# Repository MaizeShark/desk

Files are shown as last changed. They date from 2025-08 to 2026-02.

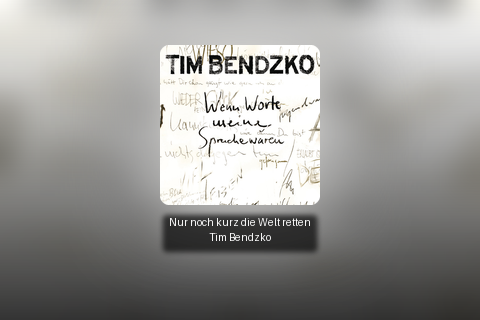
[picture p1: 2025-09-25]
htdocs/artwork.png

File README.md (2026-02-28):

# Desk

A custom-built smart L-shaped desk with deep Home Assistant integration. The project spans hardware design (custom PCBs), embedded firmware (ESP32-S3), and software services, all tied together via MQTT.

## Overview

This repository contains all the design files and software for a DIY smart desk ecosystem. The desk houses a dedicated electronics enclosure that handles audio routing, thermal management, environmental monitoring, and a media display — all controllable from Home Assistant.

```
desk/
├── PCB/            # Main KiCad PCB & schematics (ESP32-S3, DSP, DACs, PSU, …)
├── HID/            # Input device PCBs (rotary encoders, HID controller)
├── audio.md        # Audio matrix design document
├── fan_control.md  # Fan controller design document
├── Raspi/          # MPRIS-to-MQTT bridge service (Python, systemd)
└── UI/Docker/      # Media artwork generator & HTTP server (Docker)
```

---

## Sub-Projects

| | |
|---|---|
| [Audio Matrix](audio.md) | 6-in / 4-out digital audio matrix at 96 kHz / 24-bit. ADAU1451 DSP with ASRC, controlled by ESP32-S3 over I²C. Sources include USB, S/PDIF, Bluetooth (LDAC), I²S, and analog line-in. |
| [Fan Controller](fan_control.md) | ESP32-S3 reads all component temperatures via a TI TMP468 and the Raspberry Pi's CPU temp over I²C, then drives an Arctic P8 Max PWM fan based on the system hotspot. |
| [Desk GUI](https://github.com/MaizeShark/desk-gui) | ESP32-S3 firmware (PlatformIO / LVGL) for the 4-inch touchscreen control panel. Shows current track and album art, Spotify playback controls, and drives 12× addressable RGB LEDs. |
| [MPRIS → MQTT](Raspi/) | Python systemd service on the Raspberry Pi that watches the active media player via D-Bus and publishes playback state to MQTT. See [`Raspi/README.md`](Raspi/README.md). |
| [Media Artwork Service](UI/Docker/) | Dockerised service that fetches album art from Spotify / Jellyfin, composites a 480×320 image, serves it over HTTP, and publishes the URL to MQTT. See [`UI/Docker/README.md`](UI/Docker/README.md). |

---

## Hardware

The main PCB (`PCB/Tisch.kicad_pcb`) integrates all of the above subsystems onto a single board. Schematics are split into logical sheets:

| File | Content |
|---|---|
| `esp32.kicad_sch` | Main ESP32-S3 controller |
| `ADAU1451.kicad_sch` | DSP |
| `dac.kicad_sch` | PCM5122 DAC outputs |
| `adc.kicad_sch` | PCM1809 ADC input |
| `QCC5125.kicad_sch` | Bluetooth RX |
| `bm83.kicad_sch` | Bluetooth TX |
| `spdif.kicad_sch` | S/PDIF receiver |
| `raspi.kicad_sch` | Raspberry Pi interface |
| `fan.kicad_sch` | Fan control circuit |
| `psu.kicad_sch` | Power supply |
| `display.kicad_sch` | Display connector |
| `hid.kicad_sch` | HID / encoder inputs |

The `HID/` directory contains a separate PCB for the rotary encoder input device.

---

## License

This project is licensed under the **GNU General Public License v3.0**. See [`LICENSE`](LICENSE) for details.

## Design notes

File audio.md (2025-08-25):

# Project: The HA-Integrated Digital Audio Matrix

## 1. Overview

This document outlines the architecture for a high-fidelity, versatile digital audio matrix and switcher. The system is designed to manage multiple analog and digital audio sources, process them in a central DSP, and route them to various outputs. The entire system is designed to be controlled remotely via Home Assistant (HA) using the MQTT protocol, providing a seamless smart-home integration.

The core design philosophy is to achieve maximum audio quality (96 kHz / 24-bit) and routing flexibility while maintaining a modular, robust, and DIY-friendly architecture.

## 2. Core Features

*   **Flexible 6-Input / 4-Output Matrix:** Mix and route up to 6 stereo sources to 4 independent stereo destinations.
*   **High-Fidelity Audio Path:** End-to-end 96 kHz / 24-bit audio processing.
*   **Comprehensive Connectivity:**
    *   **Inputs:** USB-C (Laptop), USB-C (Phone), S/PDIF (PC), Bluetooth RX (LDAC), Raspberry Pi (I²S), and Analog Line-In (AUX).
    *   **Outputs:** 3x Analog Line-Out (Stereo), Bluetooth TX.
*   **Asynchronous Source Mixing:** A core DSP with integrated Asynchronous Sample Rate Converters (ASRCs) allows simultaneous mixing of digital sources with different clocks (e.g., USB and S/PDIF) without artifacts.
*   **Home Assistant Integration:** Full control over source selection, volume, muting, and presets via MQTT.
*   **Visual DSP Programming:** The audio signal flow (mixing, EQ, dynamics) is configured graphically using Analog Devices' SigmaStudio, drastically reducing firmware complexity.
*   **DIY-Friendly Component Choices:** Prioritizes components in easier-to-solder packages (where possible) and modular, pre-built boards for complex parts (like XMOS).

## 3. System Architecture Diagram

This diagram illustrates the flow of audio and control signals throughout the system.

```mermaid
graph TD
    subgraph " "
        %% Define Styles for Clarity
        style DSP fill:#d5a6bd,stroke:#333,stroke-width:2px
        style CONTROLLER fill:#a6c4d5,stroke:#333,stroke-width:2px
        style CLOCK fill:#a6d5b9,stroke:#333,stroke-width:2px
        style ADC fill:#f0e68c,stroke:#333
        style DAC fill:#f0b27a,stroke:#333
        style BRIDGE fill:#d2b4de,stroke:#333
        style IO fill:#fafafa,stroke:#666
    end

    subgraph Inputs
        direction LR
        LAPTOP[USB-C In <br> Laptop]:::IO
        PHONE[USB-C In <br> Phone]:::IO
        PC[S/PDIF In <br> PC]:::IO
        PI[I²S In <br> Raspberry Pi]:::IO
        BT_RX[Bluetooth RX <br> QCC5125 Module]:::IO
        AUX[Line-In <br> AUX]:::IO
    end

    subgraph "Input Interfaces & Converters"
        direction TB
        USB_SWITCH(TS3USB221 <br> USB Switch):::BRIDGE
        XMOS(XMOS XU208 <br> USB to I²S):::BRIDGE
        SPDIF_RX(DIR9001 <br> S/PDIF to I²S):::BRIDGE
        ADC(PCM1809 <br> Stereo ADC):::ADC
    end

    subgraph "Digital Core"
        direction TB
        DSP(<b>ADAU1451 DSP</b> <br> The Audio Hub):::DSP
        CONTROLLER(<b>ESP32-S3 WROOM</b> <br> The Brain):::CONTROLLER
        CLOCK_SECTION(<b>Clocking Subsystem</b>):::CLOCK
    end

    subgraph "Output Interfaces & Converters"
        direction TB
        DAC1(PCM5122 <br> Stereo DAC):::DAC
        DAC2(PCM5122 <br> Stereo DAC):::DAC
        DAC3(PCM5122 <br> Stereo DAC):::DAC
    end

    subgraph Outputs
        direction LR
        AUX_OUT[Line-Out <br> AUX]:::IO
        SPEAKERS[Line-Out <br> Desktop Speakers]:::IO
        AMP[Line-Out <br> Stereo Amp]:::IO
        BT_TX[Bluetooth TX <br> BM83 Module]:::IO
    end

    subgraph "External Control"
        HA[Home Assistant]
    end

    %% --- Connections ---

    %% Inputs to Bridges
    LAPTOP --o|USB D+/D-| USB_SWITCH
    PHONE --o|USB D+/D-| USB_SWITCH
    USB_SWITCH -->|USB D+/D-| XMOS
    PC -->|S/PDIF| SPDIF_RX
    AUX -->|Analog Audio| ADC

    %% Bridges/Sources to DSP
    XMOS -->|I²S Stream| DSP
    SPDIF_RX -->|I²S Stream| DSP
    BT_RX -->|I²S Stream| DSP
    PI -->|I²S Stream| DSP
    ADC -->|I²S Stream| DSP

    %% DSP to Output Converters
    DSP -->|I²S Stream 1| DAC1
    DSP -->|I²S Stream 2| DAC2
    DSP -->|I²S Stream 3| DAC3
    DSP -->|I²S Stream 4| BT_TX

    %% Output Converters to Physical Outputs
    DAC1 -->|Analog Audio| AUX_OUT
    DAC2 -->|Analog Audio| SPEAKERS
    DAC3 -->|Analog Audio| AMP

    %% Control Path
    HA -.->|MQTT over Wi-Fi| CONTROLLER
    CONTROLLER -.->|I²C Control| DSP
    CONTROLLER -.->|GPIO Select| USB_SWITCH

    %% Clocking Path
    subgraph " "
        XO[24.576 MHz XO] --> CLOCK_BUFFER[CDCLVC1104 <br> Clock Buffer]
    end
    CLOCK_SECTION --- CLOCK_BUFFER
    CLOCK_BUFFER ==>|MCLK| DSP
    CLOCK_BUFFER ==>|MCLK| ADC
    CLOCK_BUFFER ==>|MCLK| DAC1
    CLOCK_BUFFER ==>|MCLK| DAC2
    CLOCK_BUFFER ==>|MCLK| DAC3

```

## 4. Component Selection & Rationale

| # | Component | Qty | Part Number / Type | Rationale (Why this part?) |
|---|---|---|---|---|
| 1 | **Controller** | 1 | `ESP32-S3-WROOM-1U-N8` | **Robust & Future-Proof:** Provides ample Flash (8MB) for future projects. The **`1U`** variant with a U.FL connector is critical for reliable Wi-Fi/Bluetooth performance in a custom enclosure by allowing an external antenna. |
| 2 | **DSP** | 1 | `Analog Devices ADAU1451` | **The Heart of the System:** Powerful enough for all mixing and EQ tasks. Its **integrated ASRCs are non-negotiable** for this project, as they allow clean, simultaneous mixing of asynchronous digital sources (USB, S/PDIF, etc.) without requiring an expensive external SRC chip. |
| 3 | **USB Switch** | 1 | `TI TS3USB221DRCR` | **Smart & Cost-Effective:** Allows two USB-C ports (Laptop, Phone) to share a single, expensive XMOS bridge. The **`DRCR`** (VSON) package is significantly easier to solder in a DIY context than the smaller UQFN variant. |
| 4 | **USB-I²S Bridge**| 1 | `XMOS XU208` Module | **The Industry Standard:** Provides high-quality, driverless USB Audio Class 2 (UAC2) functionality. The **XU208** is fully capable of 96kHz stereo and is a more cost-effective choice than the newer XU316 for this application. Using a pre-made module from a source like AliExpress simplifies the design significantly. |
| 5 | **S/PDIF-I²S Bridge**| 1 | `TI DIR9001` | **Reliable & Simple:** A dedicated, robust S/PDIF receiver that provides a clean I²S stream to the DSP. A proven solution for this specific task. |
| 6 | **Bluetooth RX** | 1 | `QCC5125` Module | **High-Quality Wireless:** Supports the LDAC codec, enabling the highest possible audio quality over Bluetooth. The module provides a direct I²S output for seamless integration with the DSP. |
| 7 | **ADC (Analog)** | 1 | `TI PCM1809` | **Superior Analog Input:** An excellent replacement for the older PCM1808. It offers better performance and, crucially, **does not require external DC-blocking capacitors**, simplifying the analog layout and saving component costs. The TSSOP package is DIY-friendly. |
| 8 | **DACs (Analog)** | 3 | `TI PCM5122` | **The Pragmatic Choice:** Excellent audio performance (112 dB SNR) that is more than sufficient for the target outputs. Its **DirectPath™ technology eliminates the need for large DC-blocking output capacitors**, which saves space and cost. The **TSSOP package** is vital for easy hand-soldering. |
| 9 | **Bluetooth TX** | 1 | `BM83` Module | A capable module that can accept an I²S stream from the DSP and transmit it over Bluetooth, completing the wireless output chain. |
| 10 | **Clock Oscillator**| 1 | `24.576 MHz XO` | **The Foundation of Quality:** This frequency is a perfect integer multiple of audio rates like 48kHz and 96kHz, allowing the DSP's PLL to generate extremely stable, low-jitter system clocks. |
| 11 | **Clock Buffer** | 1 | `TI CDCLVC1104` | **Ensures Signal Integrity:** Takes the single, high-quality clock signal from the XO and distributes clean, strong, and perfectly synchronized copies to all critical audio ICs (DSP, ADC, DACs). This is essential for maintaining low jitter across the entire system. |

## 5. Signal Flow & Control Logic

### Audio Path
1.  **Input:** An audio signal arrives at one of the inputs (e.g., USB from the laptop).
2.  **Conversion:** The corresponding bridge/converter (e.g., the XMOS XU208) converts the signal into a standard I²S digital audio stream. Analog signals are first digitized by the PCM1809 ADC.
3.  **Synchronization:** The I²S stream enters the ADAU1451 DSP. Because the source is asynchronous, the DSP's internal **ASRC** immediately re-clocks the stream to the system's master clock, eliminating any source jitter.
4.  **Processing:** Inside the DSP's core, the now-synchronized audio is mixed with other active sources. Volume, EQ, and other effects (as designed in SigmaStudio) are applied.
5.  **Routing:** The final processed stereo stream is routed to one of the DSP's serial output ports.
6.  **Output:** The I²S stream is sent to the designated output converter (e.g., a PCM5122 DAC), which converts it back to an analog signal for the speakers.

### Control Path
1.  **User Action:** The user changes a setting in the Home Assistant dashboard (e.g., slides the "Desktop Speakers" volume to 50%).
2.  **MQTT Message:** Home Assistant publishes an MQTT message to a specific topic, e.g., `audio/mixer/volume/desktop`, with the payload `50`.
3.  **ESP32 Receives:** The ESP32, connected to Wi-Fi and subscribed to that topic, receives the message.
4.  **Translate & Send:** The ESP32 firmware parses the message and translates it into an I²C command for the DSP. For example, it knows that "Desktop Speakers Volume" corresponds to writing the value for 50% to a specific register address in the ADAU1451.
5.  **DSP Executes:** The ADAU1451 receives the I²C command and instantly updates the gain parameter in its active DSP program. The volume changes smoothly and immediately.

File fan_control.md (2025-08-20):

## Projektplan: Intelligente Lüftersteuerung für High-Fidelity Mediaplayer

## 1. Zielsetzung & Übersicht

Entwicklung eines fortschrittlichen, zentral gesteuerten thermischen Managementsystems für ein High-Fidelity-Mediaplayer-System. Das System soll **Multi-Zonen-fähig** sein und die Temperaturen aller kritischen Hitzekomponenten überwachen. Die Steuerung des leistungsstarken **Arctic P8 Max** PWM-Lüfters erfolgt proaktiv und geräuschoptimiert, basierend auf dem heißesten Punkt des Gesamtsystems.

Die Steuerungslogik wird vollständig auf einen **ESP32-S3** ausgelagert, um den **Raspberry Pi Zero 2W** maximal für seine primäre Audio/Video-Aufgabe zu entlasten.

## 2. Systemarchitektur

Das System basiert auf einer klaren Master-Slave-Architektur mit dem ESP32-S3 als zentralem Controller.

```mermaid
graph TD
    subgraph "Steuerungseinheit (ESP32-S3)"
        A[🧠 ESP32-S3]
    end

    subgraph "Sensoren & Aktoren"
        B[🌡️ TI TMP468 Multi-Sensor]
        C[💨 Arctic P8 Max Lüfter]
    end

    subgraph "Überwachte Komponenten"
        D[Raspberry Pi Zero 2W]
        E[ADAU1451 DSP]
        F[Verstärker]
        G[DACs / ADC]
    end

    A -- "I²C Master" --> B
    A -- "I²C Master" --> D
    A -- "PWM Steuerung" --> C

    B -- "Sensorleitungen" --> E
    B -- "Sensorleitungen" --> F
    B -- "Sensorleitungen" --> G

    D -- "CPU Temp via I²C" --> A
```

* **Gehirn (Master):** Der **ESP32-S3** agiert als I²C-Master. Er sammelt alle Daten, führt die Lüfterlogik aus und steuert den Lüfter.
* **Sensor-Hub:** Der **TI TMP468** dient als zentraler Messpunkt für alle analogen Komponenten. Er ist ein I²C-Slave.
* **Datenquelle:** Der **Raspberry Pi** agiert ebenfalls als I²C-Slave, um seine CPU-Temperatur auf Anfrage bereitzustellen.
* **Aktor:** Der **Arctic P8 Max** wird direkt vom ESP32-S3 über ein PWM-Signal gesteuert.

## 3. Hardware-Implementierung

### 3.1. Sensor-Verkabelung: TI TMP468

Der TMP468 wird zentral auf dem PCB platziert und über seinen I²C-Bus mit dem ESP32 verbunden.

| TMP468 Kanal | Zielkomponente | Sensortyp & Anschluss |
|:--- |:--- |:--- |
| **Kanal 1**  | **ADAU1451 DSP** | **On-Chip Thermal Diode:** `THD_P` an `D+`, `THD_M` an `D-`. |
| **Kanal 2**  | **Verstärker #1**  | **Externer Transistor (2N3904):** Kollektor+Basis an `D+`, Emitter an `D-`. |
| **Kanal 3**  | **Verstärker #2**  | **Externer Transistor (2N3904):** Wie oben. |
| **Kanal 4**  | **PCM1809 ADC** | **Externer Transistor (2N3904):** Wie oben. |
| **Kanal 5**  | **PCM5122 DAC #1** | **Externer Transistor (2N3904):** Wie oben. |
| **Kanal 6**  | **PCM5122 DAC #2** | **Externer Transistor (2N3904):** Wie oben. |
| **Kanal 7**  | **PCM5122 DAC #3** | **Externer Transistor (2N3904):** Wie oben. |
| **Kanal 8**  | *Reserve* | Frei für zukünftige Erweiterungen (z.B. Spannungswandler). |

### 3.2. Controller-Verkabelung: ESP32-S3

| ESP32-S3 Pin | Verbindung zu | Funktion |
|:--- |:--- |:--- |
| **GPIO (I²C SDA)** | `SDA` von TMP468 **und** `SDA` von Raspberry Pi | I²C Datenleitung (Pull-up benötigt) |
| **GPIO (I²C SCL)** | `SCL` von TMP468 **und** `SCL` von Raspberry Pi | I²C Taktleitung (Pull-up benötigt) |
| **GPIO (PWM)** | Blaues Kabel (Pin 4) des Arctic P8 Max | PWM-Steuersignal für den Lüfter |
| **5V** | Rotes Kabel (Pin 2) des Arctic P8 Max | 5V Spannungsversorgung für den Lüfter  |
| **GND** | Schwarzes Kabel (Pin 1) des Arctic P8 Max | Masse für Lüfter und I²C-Kommunikation |

### 3.3. Raspberry Pi Konfiguration als I²C-Slave

Der Pi wird als I²C-Slave konfiguriert, was eine zuverlässige Bibliothek erfordert. **Die beste Wahl hierfür ist `pigpio`**.

1. **Aktivieren:** `sudo raspi-config` -> `Interface Options` -> `I2C` -> `Enable`.
2. **`pigpio` Daemon starten:** Der `pigpio` Daemon muss laufen, damit das Skript funktioniert (`sudo systemctl start pigpiod`).

## 4. Kommunikationsprotokoll (ESP32 ↔ Pi)

Ein einfaches Register-basiertes Protokoll wird für die I²C-Kommunikation verwendet.

* **ESP32-S3:** I²C Master
* **Raspberry Pi:** I²C Slave (z.B. an Adresse `0x10`)

| Register (Adresse) | Lese-/Schreibzugriff  | Datenformat | Beschreibung |
|:--- |:--- |:--- |:--- |
| `0x01` | Nur Lesen (ESP32) | 1 Byte | **Ganzzahl-Anteil** der Pi CPU-Temperatur (z.B. `58` für 58.7°C). |
| `0x02` | Nur Lesen (ESP32) | 1 Byte | **Nachkomma-Anteil** der Pi CPU-Temperatur, multipliziert mit 100 (z.B. `70`). |
| `0x10` | Nur Schreiben (ESP32) | 1 Byte | Aktuelle Lüftergeschwindigkeit in % (optional, falls Pi den Status anzeigen soll). |

**Ablauf:** Der ESP32 liest zuerst Register `0x01` und dann Register `0x02` vom Pi aus, um die vollständige Temperatur zu erhalten (`58.70`).

## 5. Software-Implementierung

### 5.1. Raspberry Pi: I²C-Slave-Skript (Python)

Dieses Skript läuft als Service im Hintergrund, liest die CPU-Temperatur und stellt sie über den `pigpio` I²C-Slave-Handler bereit.

```python
# pi_i2c_slave.py
import time
import pigpio
import atexit

# --- Konfiguration ---
I2C_SLAVE_ADDRESS = 0x10  # Die I2C-Adresse, auf die der Pi hört
I2C_BUS = 1               # Standard I2C-Bus am Pi

# --- Register-Definitionen ---
REG_TEMP_INT = 0x01
REG_TEMP_FRAC = 0x02
REG_FAN_SPEED = 0x10

# Globale Variablen für den Datenaustausch
pi_temp_int = 0
pi_temp_frac = 0
fan_speed = 0

def get_cpu_temp():
    """Liest die CPU-Temperatur und gibt sie als Ganz- und Nachkomma-Teil zurück."""
    with open('/sys/class/thermal/thermal_zone0/temp', 'r') as f:
        temp_milli = int(f.read())
    temp_c = temp_milli / 1000.0
    return int(temp_c), int((temp_c * 100) % 100)

def i2c_callback(id, tick):
    """Diese Funktion wird von pigpio aufgerufen, wenn eine I2C-Aktivität stattfindet."""
    global fan_speed
    s, b, d = pi.bsc_i2c(I2C_SLAVE_ADDRESS) # Status der I2C-Transaktion abrufen

    if b > 0: # Wenn Daten geschrieben wurden (ESP32 sendet)
        # Beispiel: Lüftergeschwindigkeit vom Master empfangen
        if d[0] == REG_FAN_SPEED and b > 1:
            fan_speed = d[1]
            print(f"Lüftergeschwindigkeit vom Master erhalten: {fan_speed}%")

# --- Hauptprogramm ---
pi = pigpio.pi()
if not pi.connected:
    exit()

# Sicherstellen, dass die Ressourcen bei Skriptende freigegeben werden
atexit.register(pi.bsc_i2c, 0) 
pi.bsc_i2c(I2C_SLAVE_ADDRESS) # I2C-Slave-Modus aktivieren

print(f"I2C-Slave auf Adresse {hex(I2C_SLAVE_ADDRESS)} gestartet. Warte auf Master...")

try:
    while True:
        # 1. Aktuelle CPU-Temperatur lesen
        pi_temp_int, pi_temp_frac = get_cpu_temp()

        # 2. Datenpuffer für den I2C-Slave vorbereiten
        # pigpio erfordert eine Liste von Bytes. Wir erstellen einen 256-Byte-Puffer.
        data_buffer = [0] * 256
        data_buffer[REG_TEMP_INT] = pi_temp_int
        data_buffer[REG_TEMP_FRAC] = pi_temp_frac

        # 3. Den Slave mit den neuen Daten "füttern"
        pi.bsc_i2c(I2C_SLAVE_ADDRESS, data_buffer)

        time.sleep(2) # Aktualisierungsintervall

except KeyboardInterrupt:
    print("\nSkript beendet.")
finally:
    pi.bsc_i2c(0) # Slave deaktivieren
    pi.stop()
```

### 5.2. ESP32-S3: Controller-Software (Arduino C++ Logik)

Dies ist das Herzstück, das alle Fäden zusammenführt.

```cpp
#include <Wire.h>

// --- Konfiguration ---
#define PI_I2C_ADDR 0x10
#define TMP468_I2C_ADDR 0x4C // Beispieladresse, im Datenblatt prüfen!
#define FAN_PWM_PIN 18

// --- Lüfterkurve ---
const float FAN_START_TEMP = 55.0;
const float FAN_MAX_TEMP = 75.0;
const float FAN_MIN_SPEED = 20.0;
const float HYSTERESIS = 5.0;
bool fan_is_on = false;

// --- PWM-Setup ---
const int PWM_CHANNEL = 0;
const int PWM_FREQ = 25000;
const int PWM_RESOLUTION = 8; // 0-255

void setup() {
  Serial.begin(115200);
  Wire.begin(); // ESP32 als I2C Master starten

  // Lüfter-PWM konfigurieren
  ledcSetup(PWM_CHANNEL, PWM_FREQ, PWM_RESOLUTION);
  ledcAttachPin(FAN_PWM_PIN, PWM_CHANNEL);
  ledcWrite(PWM_CHANNEL, 0); // Lüfter initial aus
  Serial.println("System-Controller gestartet.");
}

void loop() {
  // 1. Alle Temperaturen sammeln
  float pi_temp = getPiTemperature();
  float dsp_temp = getTMP468Temperature(1);
  float amp1_temp = getTMP468Temperature(2);
  // ... weitere Sensoren abfragen

  // 2. Den heißesten Punkt im System finden ("Hotspot")
  float max_temp = 0.0;
  max_temp = max(max_temp, pi_temp);
  max_temp = max(max_temp, dsp_temp);
  max_temp = max(max_temp, amp1_temp);
  // ... alle weiteren Temperaturen vergleichen

  // 3. Lüfter-Geschwindigkeit basierend auf dem Hotspot berechnen
  int fan_speed_percent = calculateFanSpeed(max_temp);

  // 4. PWM-Signal für den Lüfter setzen
  int pwm_value = (fan_speed_percent * 255) / 100;
  ledcWrite(PWM_CHANNEL, pwm_value);

  // 5. Status ausgeben
  Serial.printf("Hotspot-Temp: %.2f°C | Pi: %.2f°C | DSP: %.2f°C | Lüfter: %d%%\n", 
                max_temp, pi_temp, dsp_temp, fan_speed_percent);

  delay(3000); // 3 Sekunden warten bis zur nächsten Messung
}

// --- Hilfsfunktionen ---

float getPiTemperature() {
  Wire.requestFrom(PI_I2C_ADDR, 2); // Fordere 2 Bytes an
  if (Wire.available() >= 2) {
    byte temp_int = Wire.read();
    byte temp_frac = Wire.read();
    return (float)temp_int + ((float)temp_frac / 100.0);
  }
  return -1.0; // Fehlerwert
}

float getTMP468Temperature(int channel) {
  // Hier kommt die Logik zum Auslesen des TMP468.
  // Dies erfordert das Senden von Befehlen an den Chip, um das
  // Register für den gewünschten Kanal auszuwählen und dann den Wert zu lesen.
  // (Beispiel, muss an Datenblatt angepasst werden)
  Wire.beginTransmission(TMP468_I2C_ADDR);
  Wire.write(0x08); // Pointer auf Remote Temp Register von Kanal X setzen
  Wire.write(1 << channel); 
  Wire.endTransmission();

  Wire.requestFrom(TMP468_I2C_ADDR, 1);
  if(Wire.available()){
    return (float)Wire.read();
  }
  return -1.0; // Fehlerwert
}

int calculateFanSpeed(float temp) {
    if (!fan_is_on && temp >= FAN_START_TEMP) {
        fan_is_on = true;
    } else if (fan_is_on && temp < (FAN_START_TEMP - HYSTERESIS)) {
        fan_is_on = false;
    }

    if (!fan_is_on) return 0;

    if (temp >= FAN_MAX_TEMP) return 100;

    float speed = FAN_MIN_SPEED + ((temp - FAN_START_TEMP) / (FAN_MAX_TEMP - FAN_START_TEMP)) * (100.0 - FAN_MIN_SPEED);
    return max((int)FAN_MIN_SPEED, min(100, (int)speed));
}
```

## 6. Zusammenfassung der Vorteile dieses Designs

* **Maximale Performance:** Der Raspberry Pi wird von allen Echtzeit-Steuerungsaufgaben befreit.
* **Ganzheitliche Kühlung:** Das System reagiert auf den *tatsächlichen* Hotspot, egal ob es der DSP, ein Verstärker oder die CPU ist.
* **Robustheit:** Klare Trennung der Aufgaben. Fällt eine Komponente aus, kann der ESP32 intelligent reagieren (z.B. Lüfter auf 100% schalten, wenn Pi nicht mehr antwortet).
* **Skalierbarkeit:** Dank des TMP468 können problemlos weitere Sensoren hinzugefügt werden.
* **Effizienz:** Der ESP32-S3 ist extrem stromsparend und perfekt für 24/7-Managementaufgaben geeignet.

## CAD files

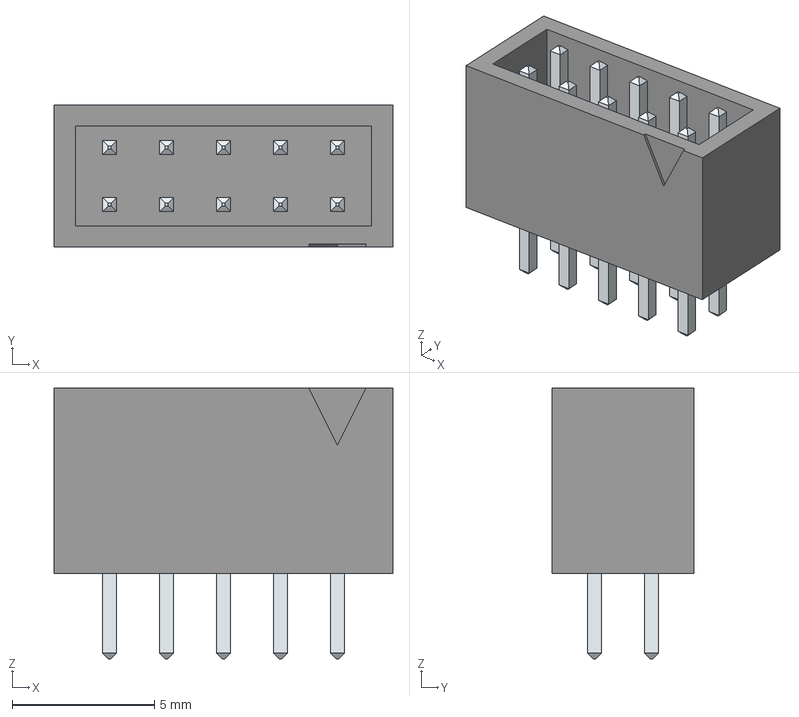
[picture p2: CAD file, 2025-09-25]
HID/librarys/B10B-PHDSS_LF__SN__P_.stp
11.9 x 5.00 x 9.50 mm
LeadsArray

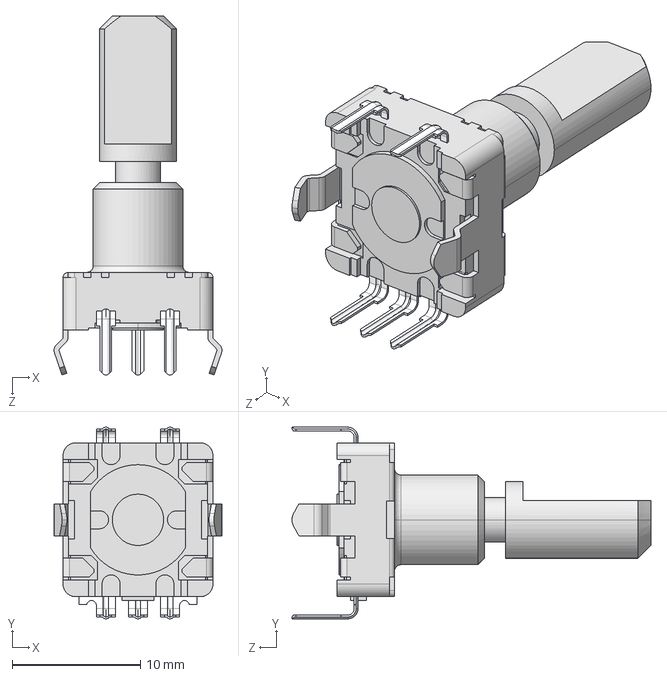
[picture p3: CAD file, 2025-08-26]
HID/librarys/EC11E15244B2.stp
13.1 x 15.0 x 28.0 mm

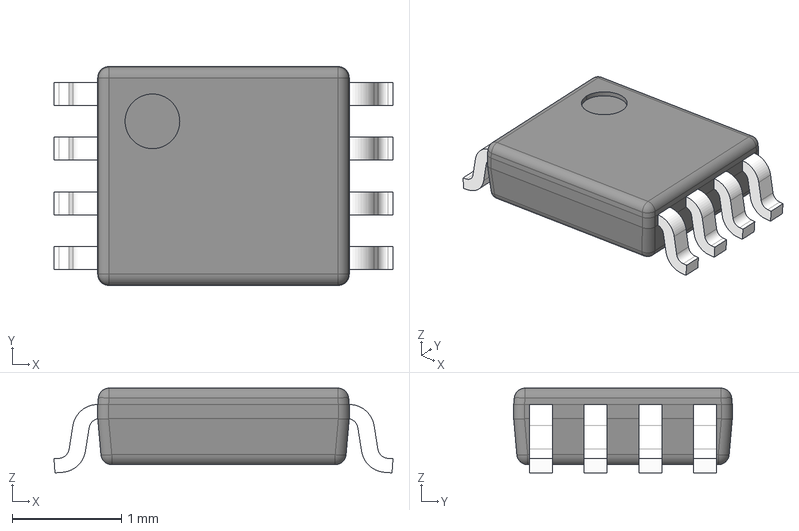
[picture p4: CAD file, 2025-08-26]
HID/librarys/SN74LVC3G17.stp
3.10 x 2.00 x 0.775 mm
BODY-VSSOP
LEAD-VSSOP x 8

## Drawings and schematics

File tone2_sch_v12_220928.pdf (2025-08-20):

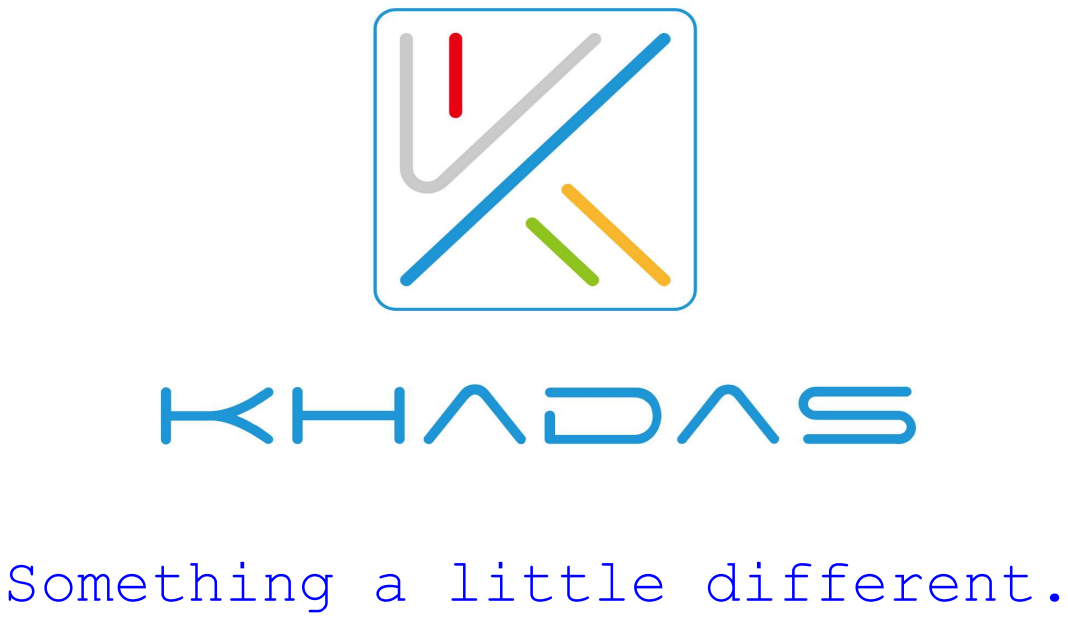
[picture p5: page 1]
Project:; Designed_by:; Rev: Sheet: Tuesday, September 27, 2022; Tone2 Eric 00_Khadas

Something a little different.

File: Date: Shenzhen Wesion Technology Co., Ltd.

# LPF

# R I/V

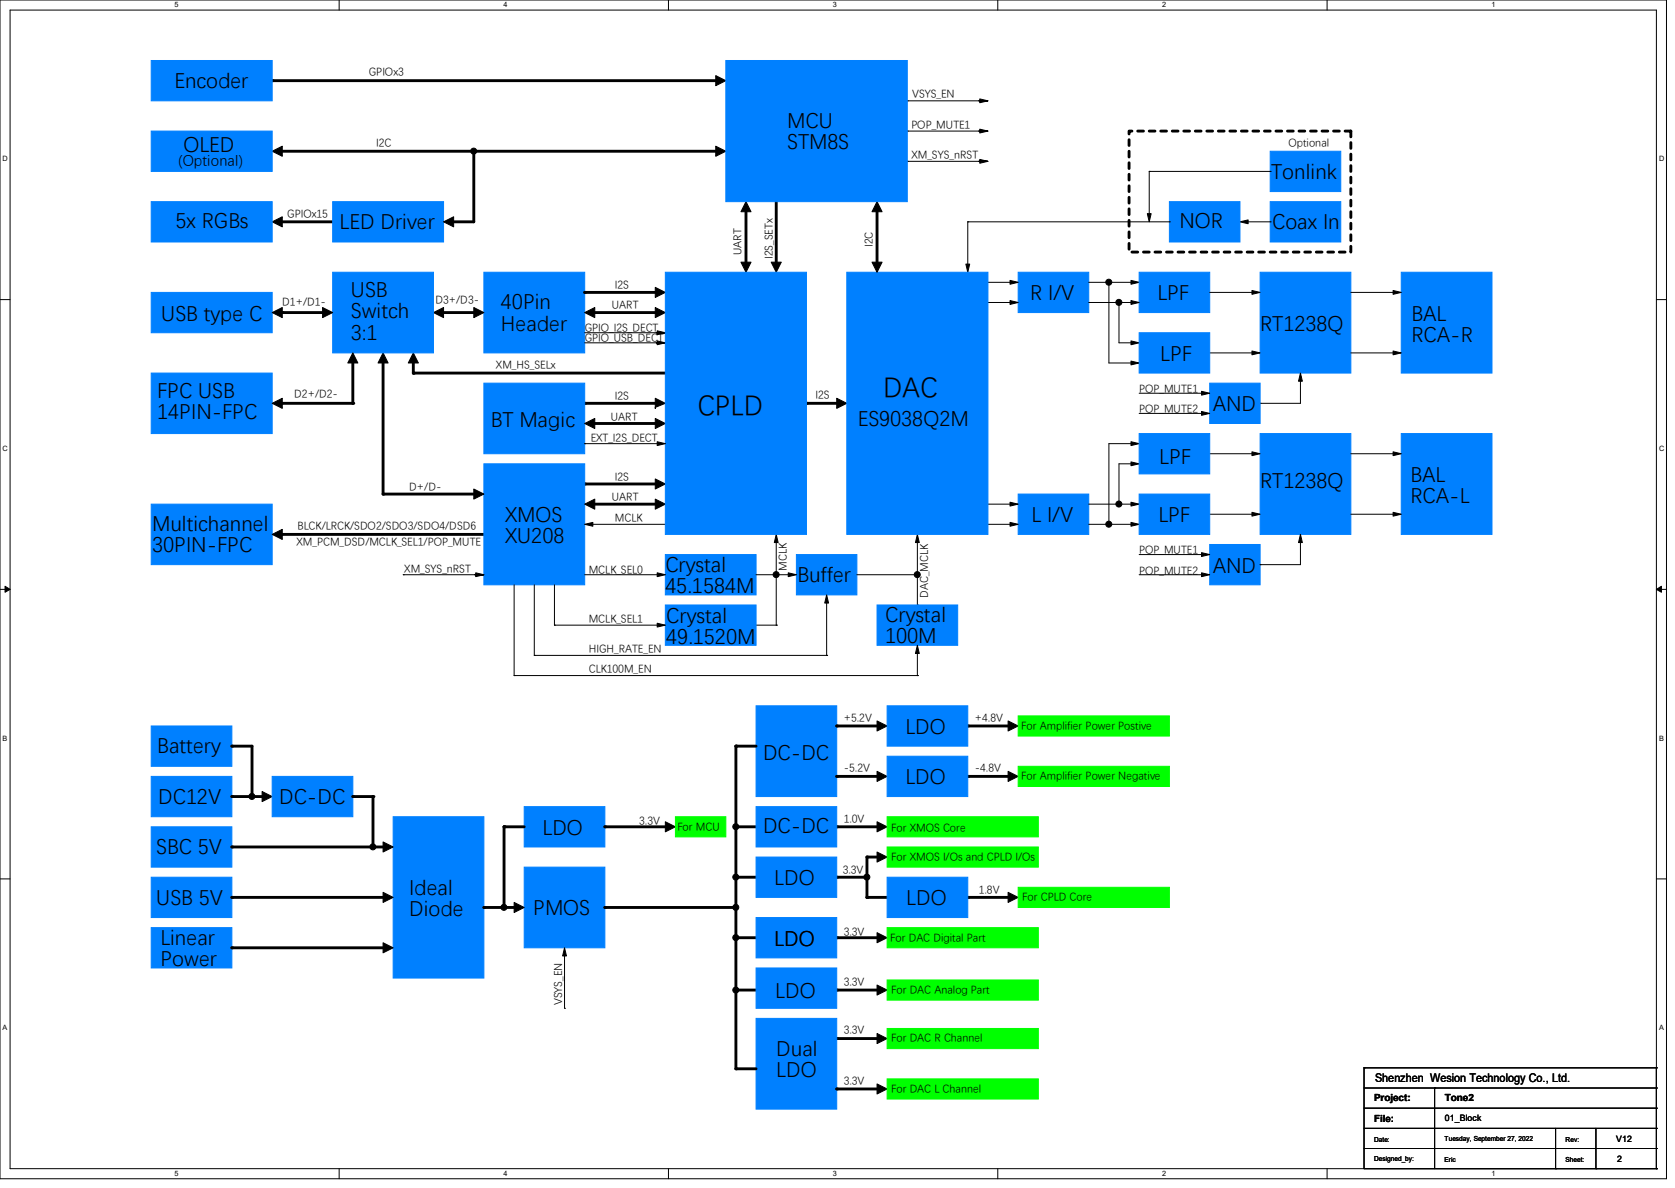
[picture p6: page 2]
POP_MUTE2; Dual LDO; Ideal Diode; Battery; Linear Power; USB 5V; LDO; POP_MUTE1; AND; SBC 5V; CPLD; LPF; BAL RCA-L; BAL RCA-R; OLED (Optional); +4.8V LDO; -4.8V LDO; For MCU; 1.0V LDO; For XMOS Core; PMOS; Coax In; XM_HS_SELx; EXT_I2S_DECT; XM_PCM_DSD/MCLK_SEL1/POP_MUTE; BLCK/LRCK/SDO2/SDO3/SDO4/DSD6; UART; GPIO_I2S_DECT GPIO_USB_DECT VSYS_EN; 5x RGBs; LED Driver GPIOx15; Crystal 49.1520M; Crystal 45.1584M; MCLK_SEL1; MCLK_SEL0; I2S_SETx UART; VSYS_EN; XM_SYS_nRST; Buffer; CLK100M_EN; MCLK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

For Amplifier Power Postive

For Amplifier Power Negative

For XMOS I/Os and CPLD I/Os
LDO

For CPLD Core

For DAC Digital Part

For DAC Analog Part

For DAC R Channel

For DAC L Channel

# USB-C Ext IO &

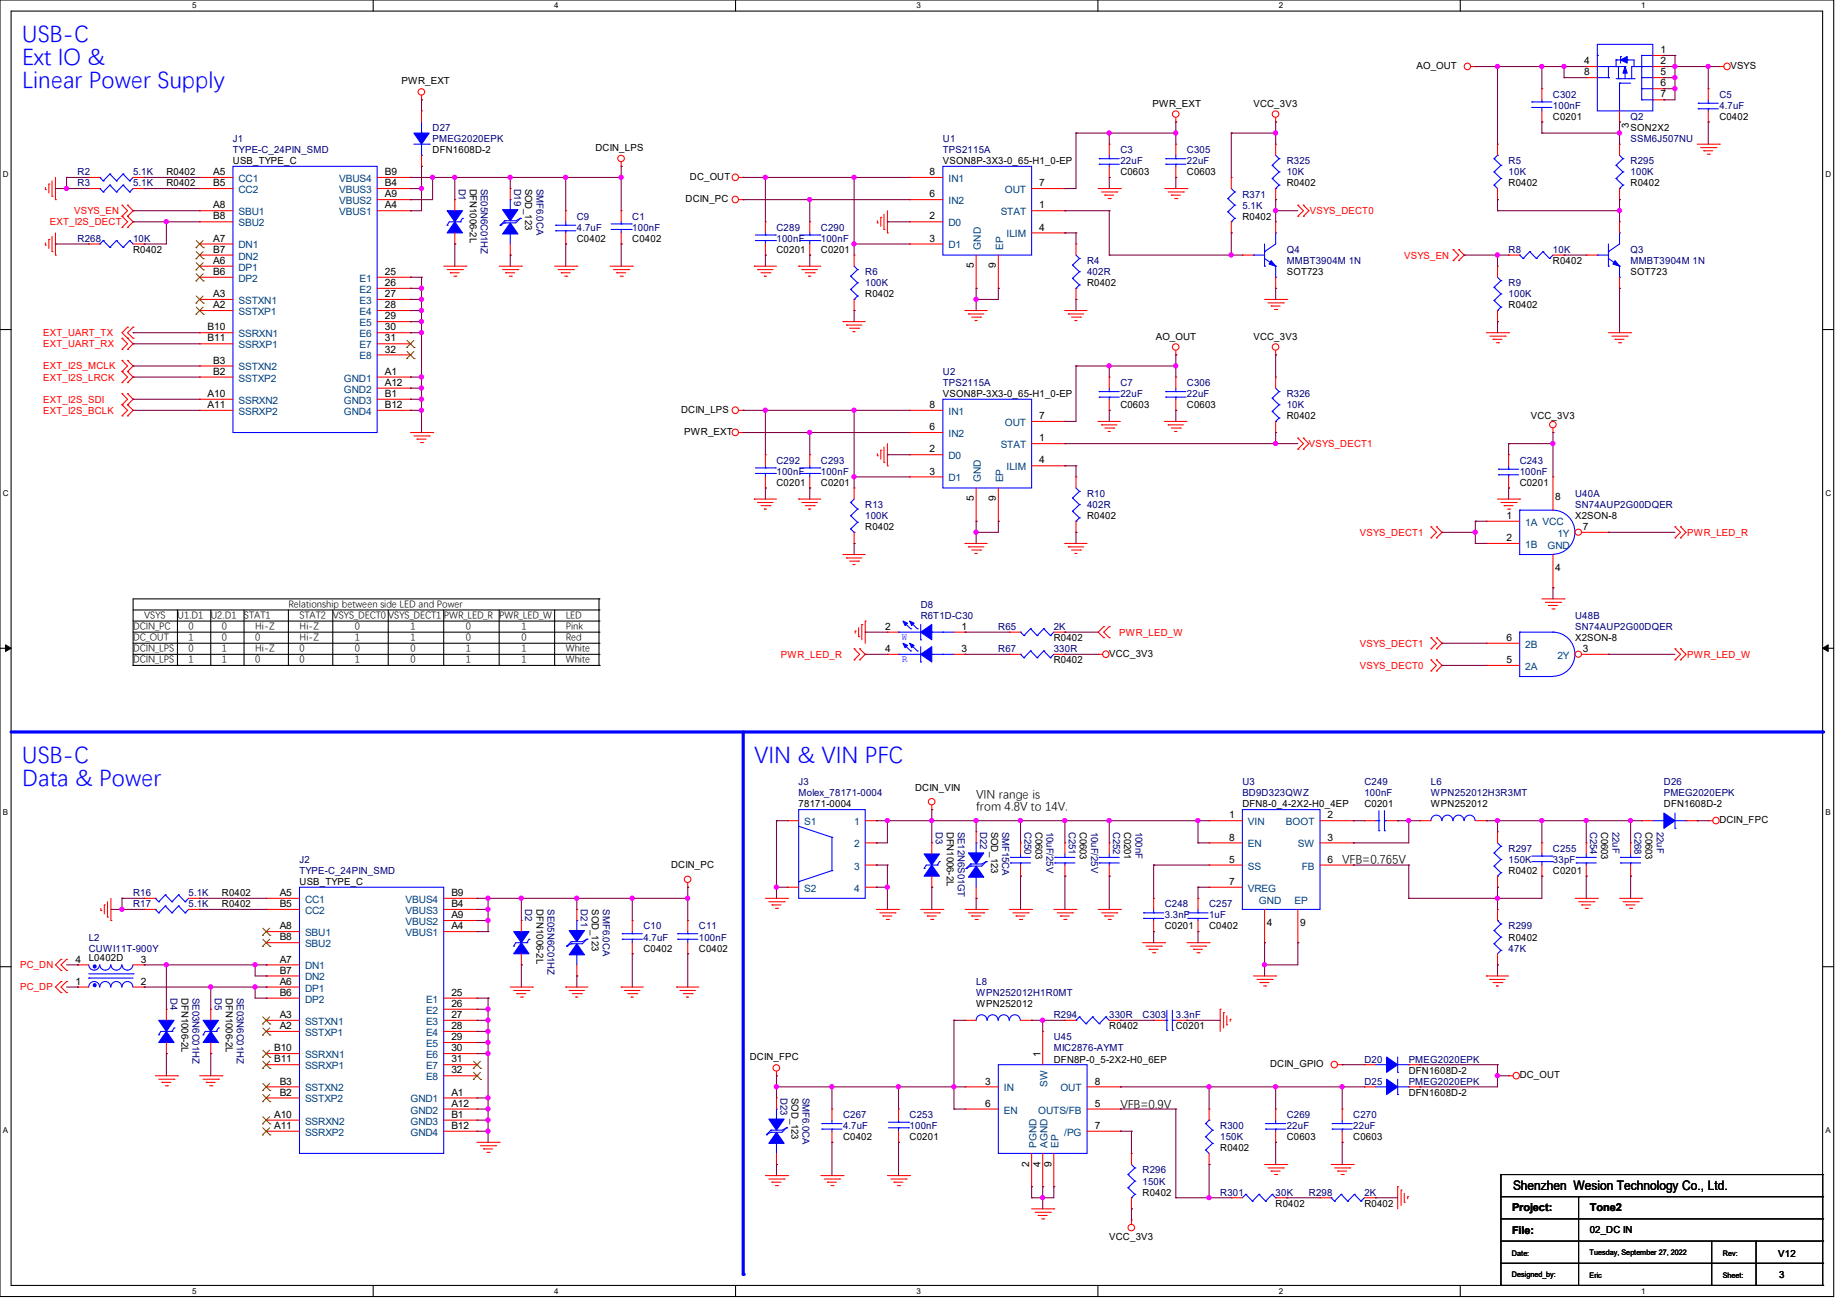
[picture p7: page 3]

Relationship between side LED and Power

VSYS | U1.D1 | U2.D1 | STAT1 | STAT2 | VSYS_DECT0 VSYS_DECT1 PWR_LED_R | | | PWR_LED_W | LED
DCIN_PC | 0 | 0 | Hi-Z | Hi-Z | 0 | 1 | 0 | 1 | Pink

DCIN_LPS | 0 | 1 | Hi-Z | 0 | 0 | 0 | 1 | 1 | White
DCIN_LPS | 1 | 1 | 0 | 0 | 1 | 0 1 | | 1 | White

# CPLD IO

# CPLD Core

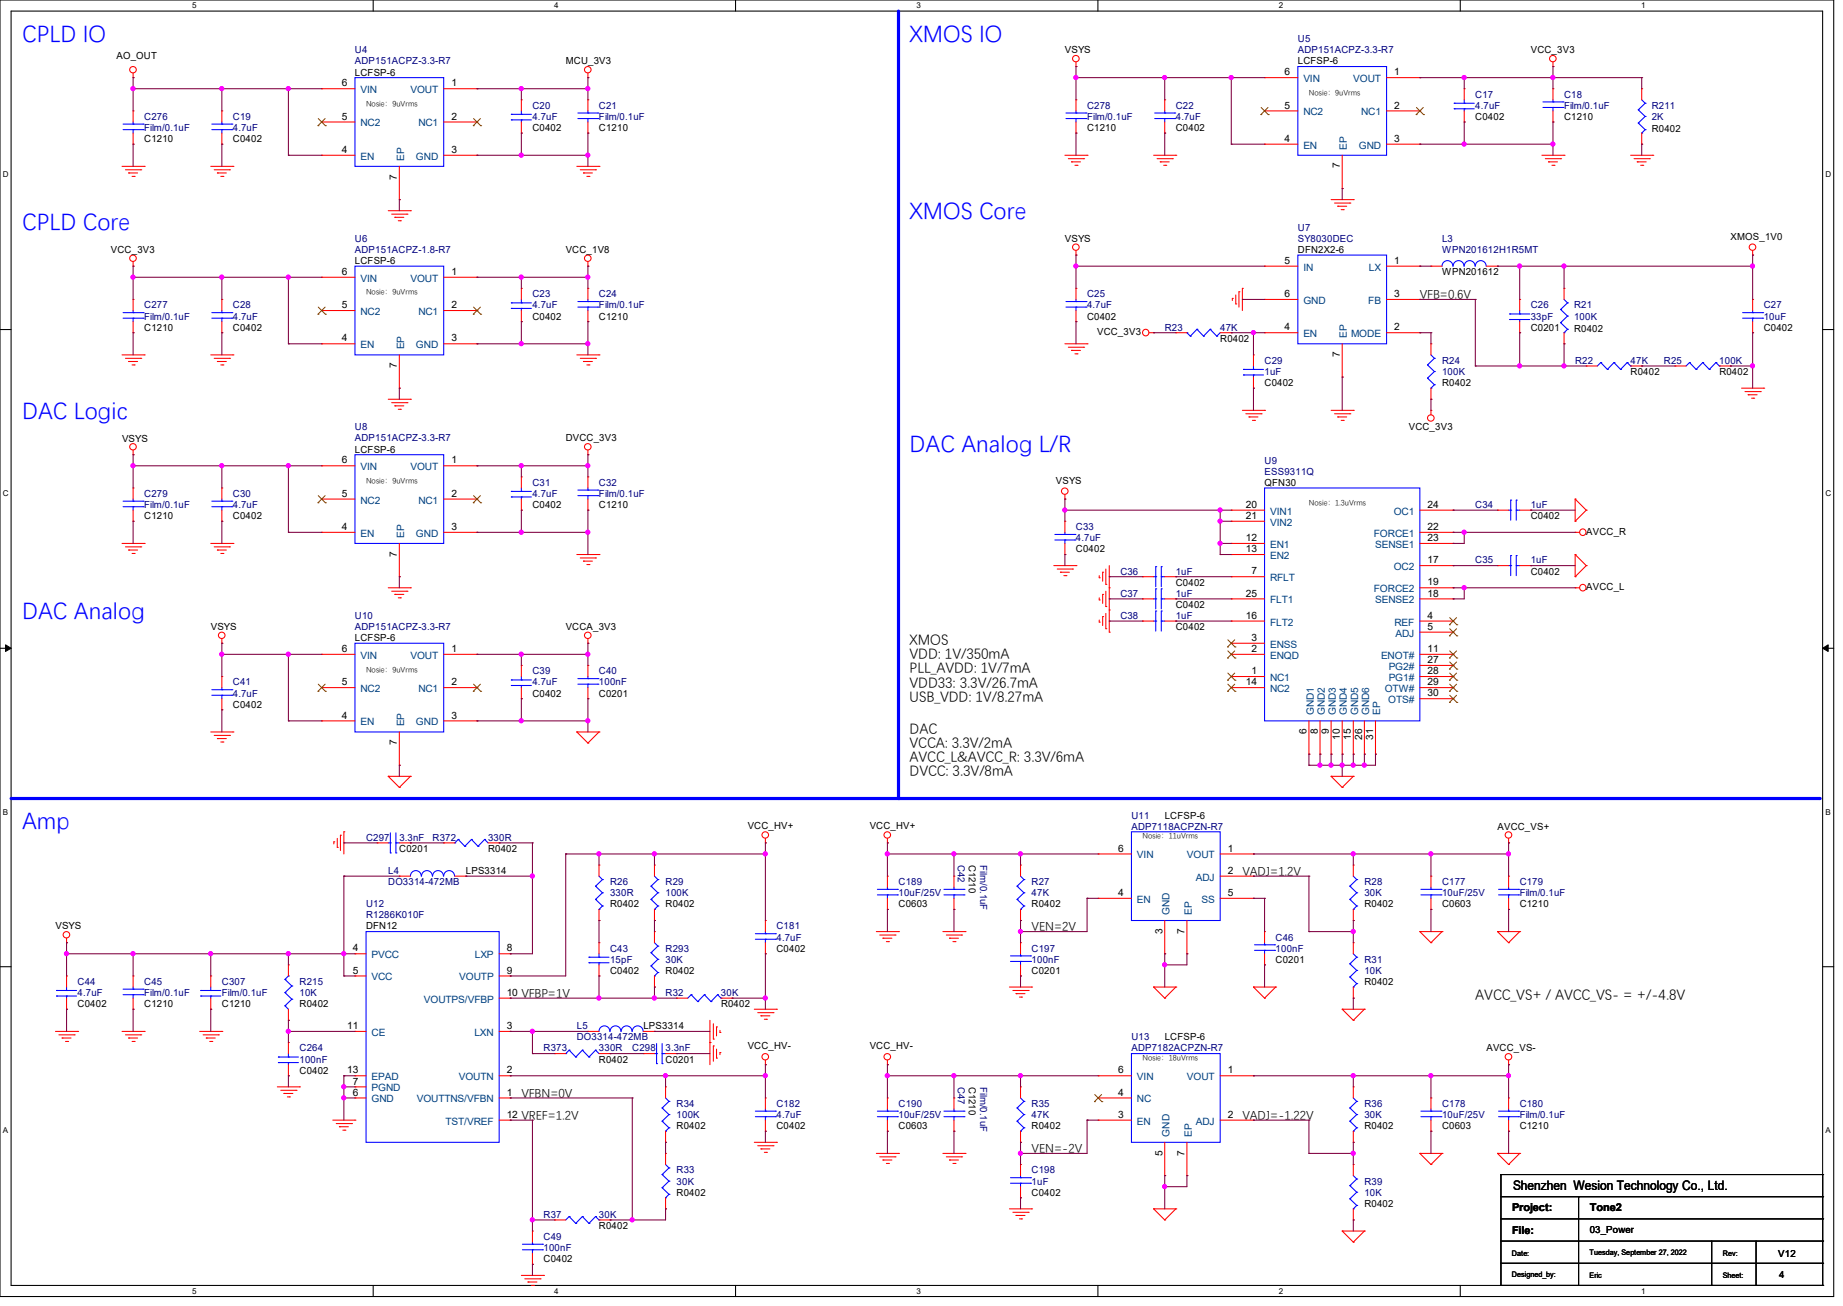
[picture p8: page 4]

9 GND4 10 ENOT# 11 EN1 12 EN2 13 NC2 14 GND5 15 FLT2 16 OC2 17 SENSE2 18 FORCE2 19 VIN1 20 VIN2 21 FORCE1 22 SENSE1 23 OC1 24 FLT1 25 GND6 26 PG2# 27 PG1# 28 OTW# 29 OTS# 30 EP 31 C17

3 EN 4 SS 5 ADJ 2 VIN 6 EP

LXN 3 PVCC 4 VCC 5 GND 6 PGND 7

5 EN 3 VOUT 1 ADJ 2 NC 4 EP

CPLD Power | CPLD IOs

# EXT_I2S_DECT XM_SPDIF_OUT

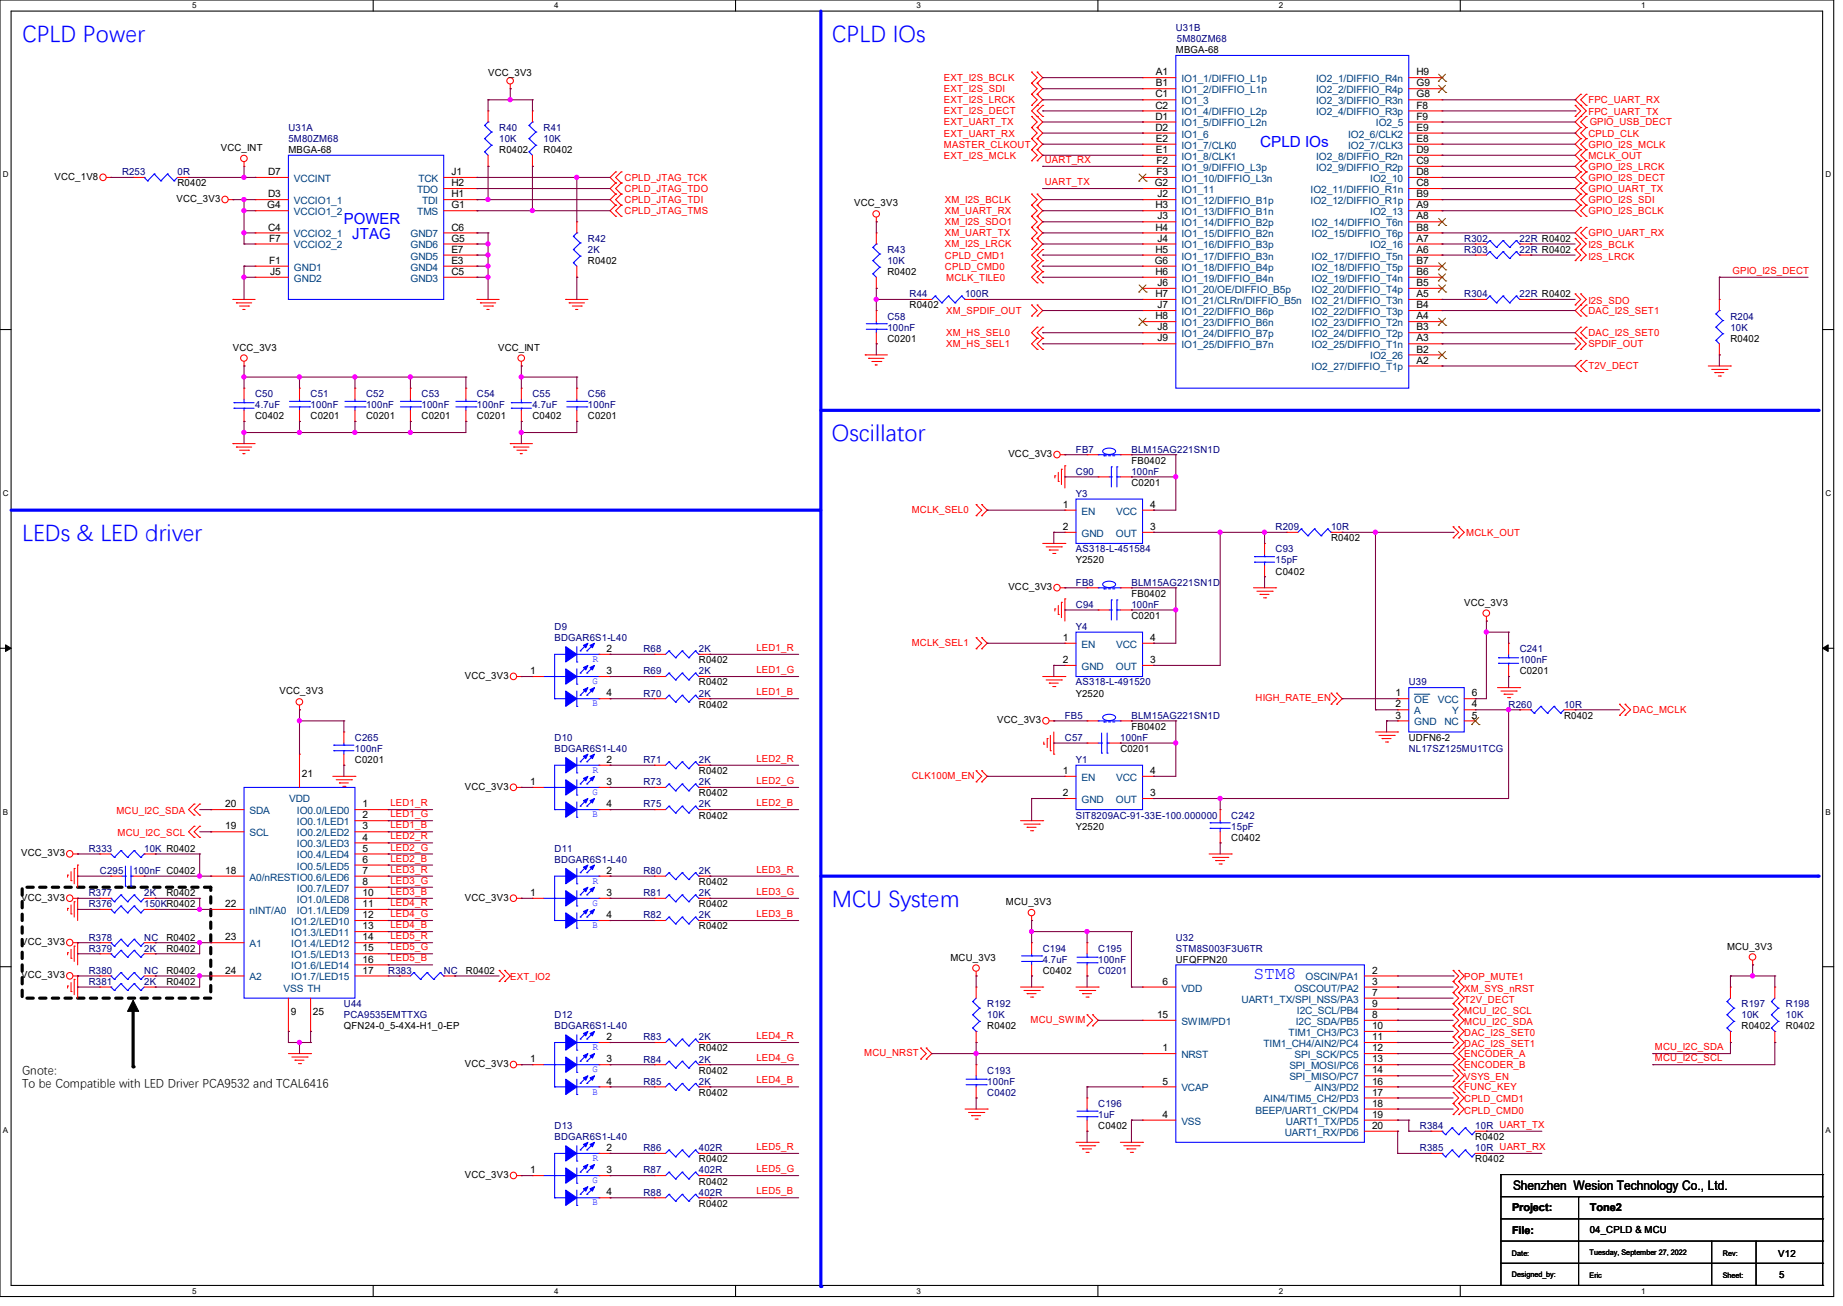
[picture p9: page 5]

Gnote:
To be Compatible with LED Driver PCA9532 and TCAL6416

# XMOS

X0D39_1P0_8D3 2 X0D41_8D5 4 X0D38_1O0_8D2 1 CLK 42 USB_VDD 22 | X0D40_8D4 3 X0D11_1D0 13 X0D26_4E0 34 TCK 44 | X0D01_1B0 9 X0D10_1C0 10 USB_DP 20 VDDIOR 31 PLL_AVDD 39 OTP_VCC 40 RST_N 41 | X0D16_4D0 27 X0D04_4B0 12 X0D07_4B3 16 USB_DM 21 | X0D19_4D3 30 VDD3 32 | X0D35_1L0 33 X0D06_4B2 15 USB_VBUS 18 USB_RTUNE 19 | X0D28_4F0 36 USB_VDD33 17 | X0D27_4E1 35 X0D29_4F1 37 VDD4 38 | X0D42_8D6 5 VDDIOL 7 VDD1 8 | X0D43_8D7 6

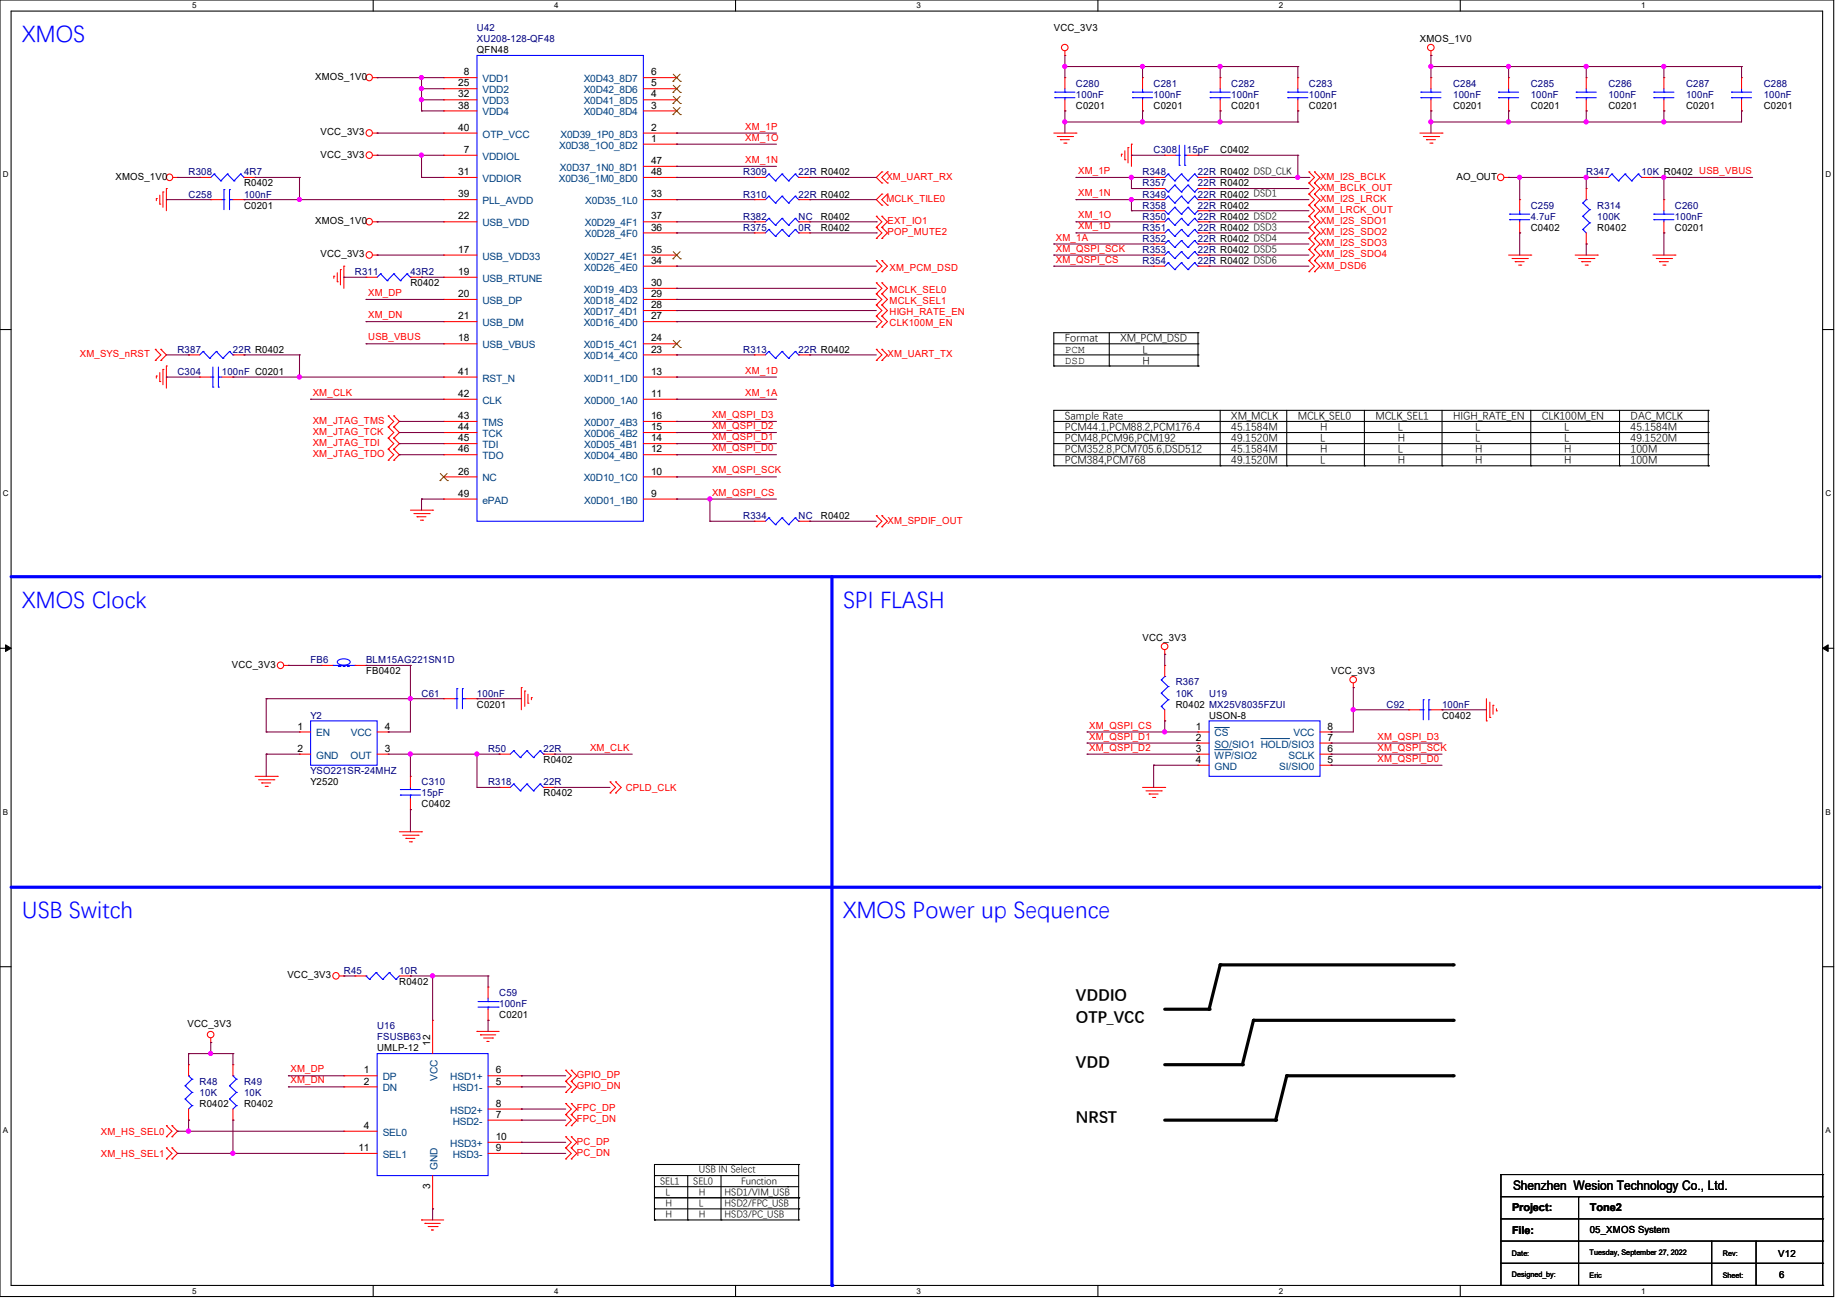
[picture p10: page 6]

PCM | L | XM_DSD6 XM_SPDIF_OUT

Format | XM_PCM_DSD
DSD | H

Sample Rate | XM_MCLK | MCLK_SEL0 | MCLK_SEL1 | HIGH_RATE_EN | CLK100M_EN | DAC_MCLK
PCM44.1,PCM88.2,PCM176.4 | 45.1584M | H | L | L | L | 45.1584M
PCM48,PCM96,PCM192 | 49.1520M | L | H | L | L | 49.1520M
PCM352.8,PCM705.6,DSD512 | 45.1584M | H | L | H | H | 100M
PCM384,PCM768 | 49.1520M | L | H | H | H | 100M

XMOS Power up Sequence

SEL1 | SEL0 | Function
L | H | HSD1/VIM_USB

DAC | SPDIF: Coaxial IN/OUT

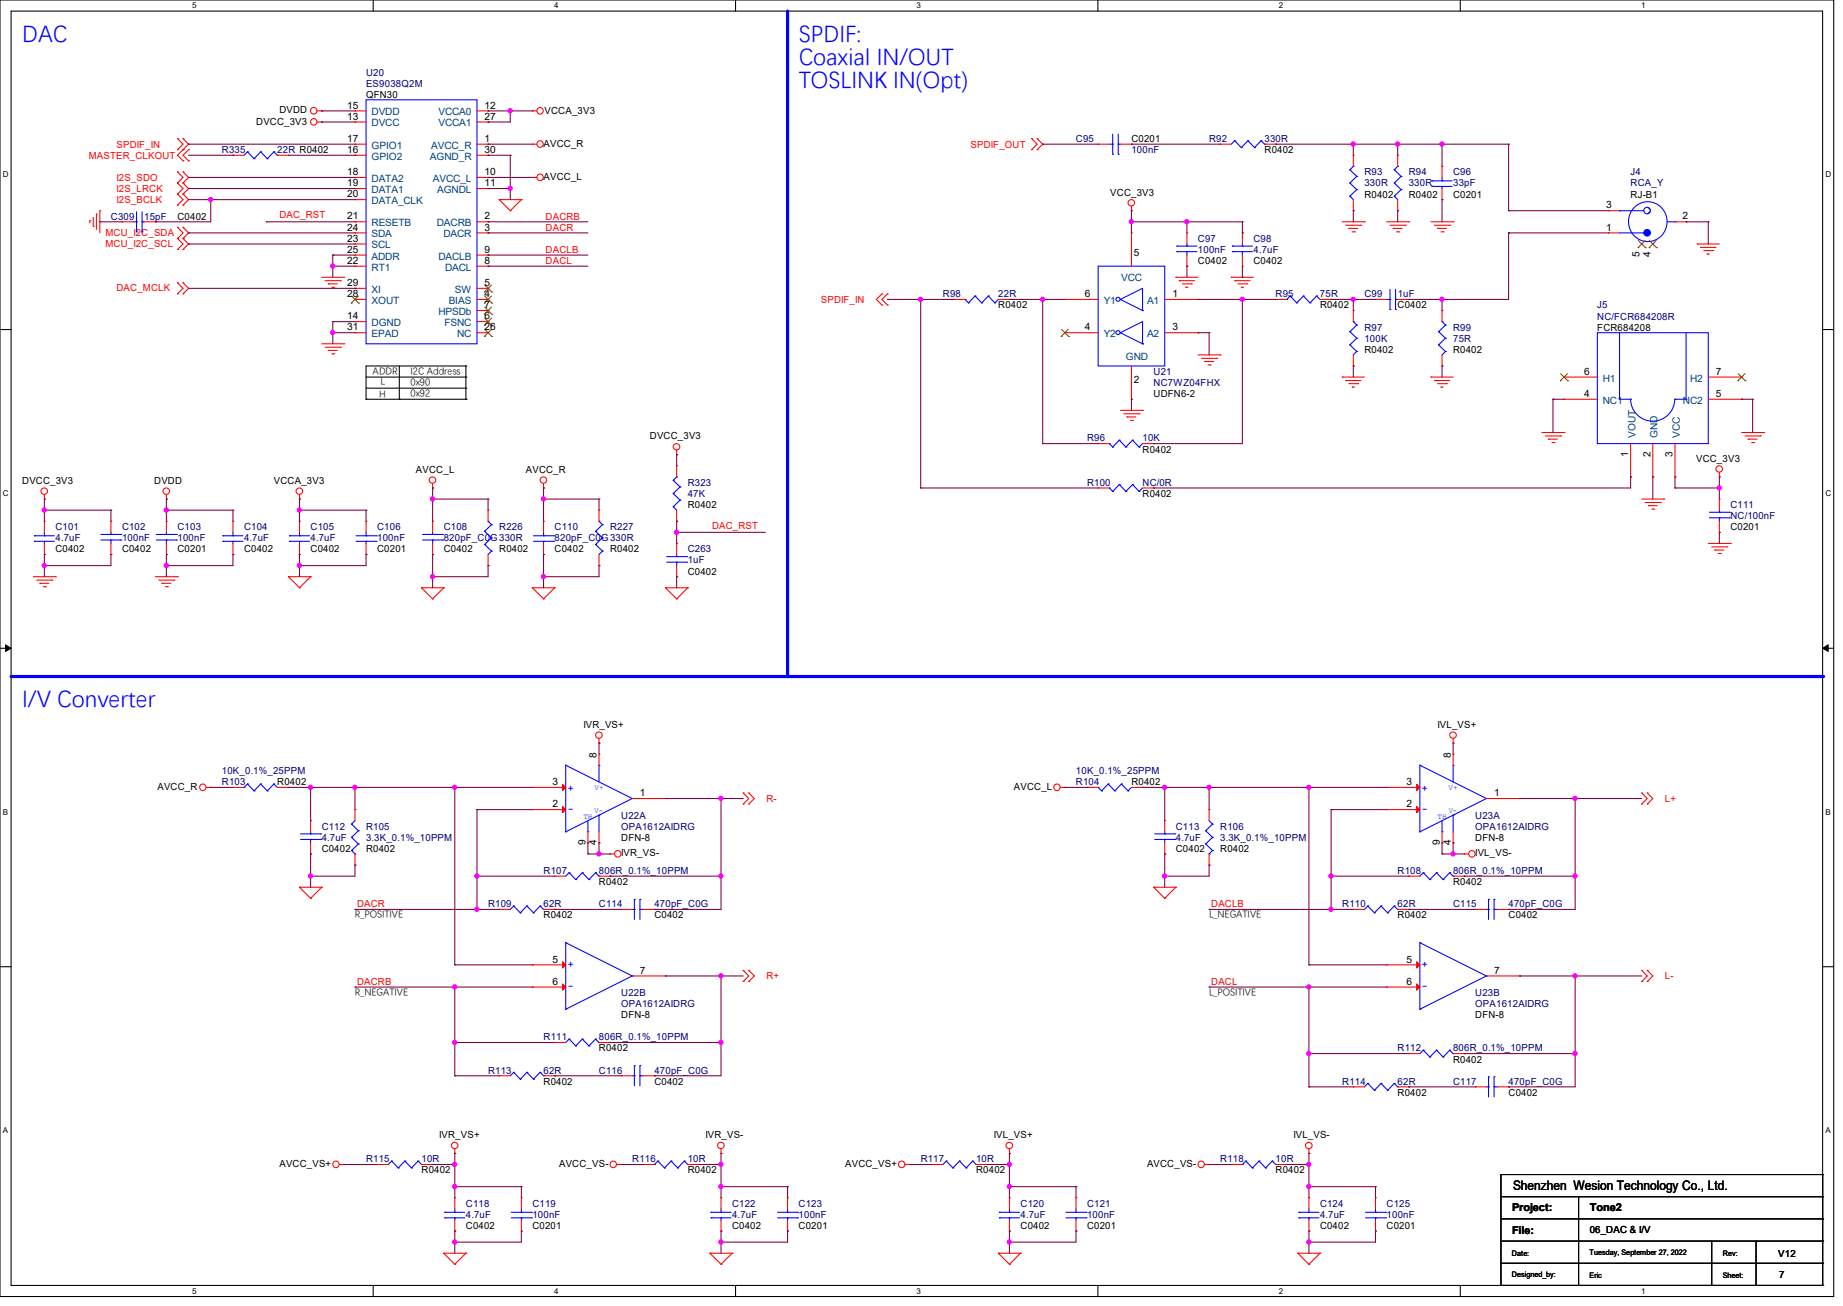
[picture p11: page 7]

ADDR | I2C Address
L 0x90
H 0x92

File: Date: Shenzhen Wesion Technology Co., Ltd. Designed_by: File: Date: Shenzhen Wesion Technology Co., Ltd. Designed_by: File: Date: Shenzhen Wesion Technology Co., Ltd. Designed_by: | Rev: Sheet: Tuesday, September 27, 2022 Tone2 Eric 06_DAC & I/V Rev: Sheet: Tuesday, September 27, 2022 Tone2 Eric 06_DAC & I/V Rev: Sheet: Tuesday, September 27, 2022 Tone2 Eric 06_DAC & I/V

# Low-Pass Filter R

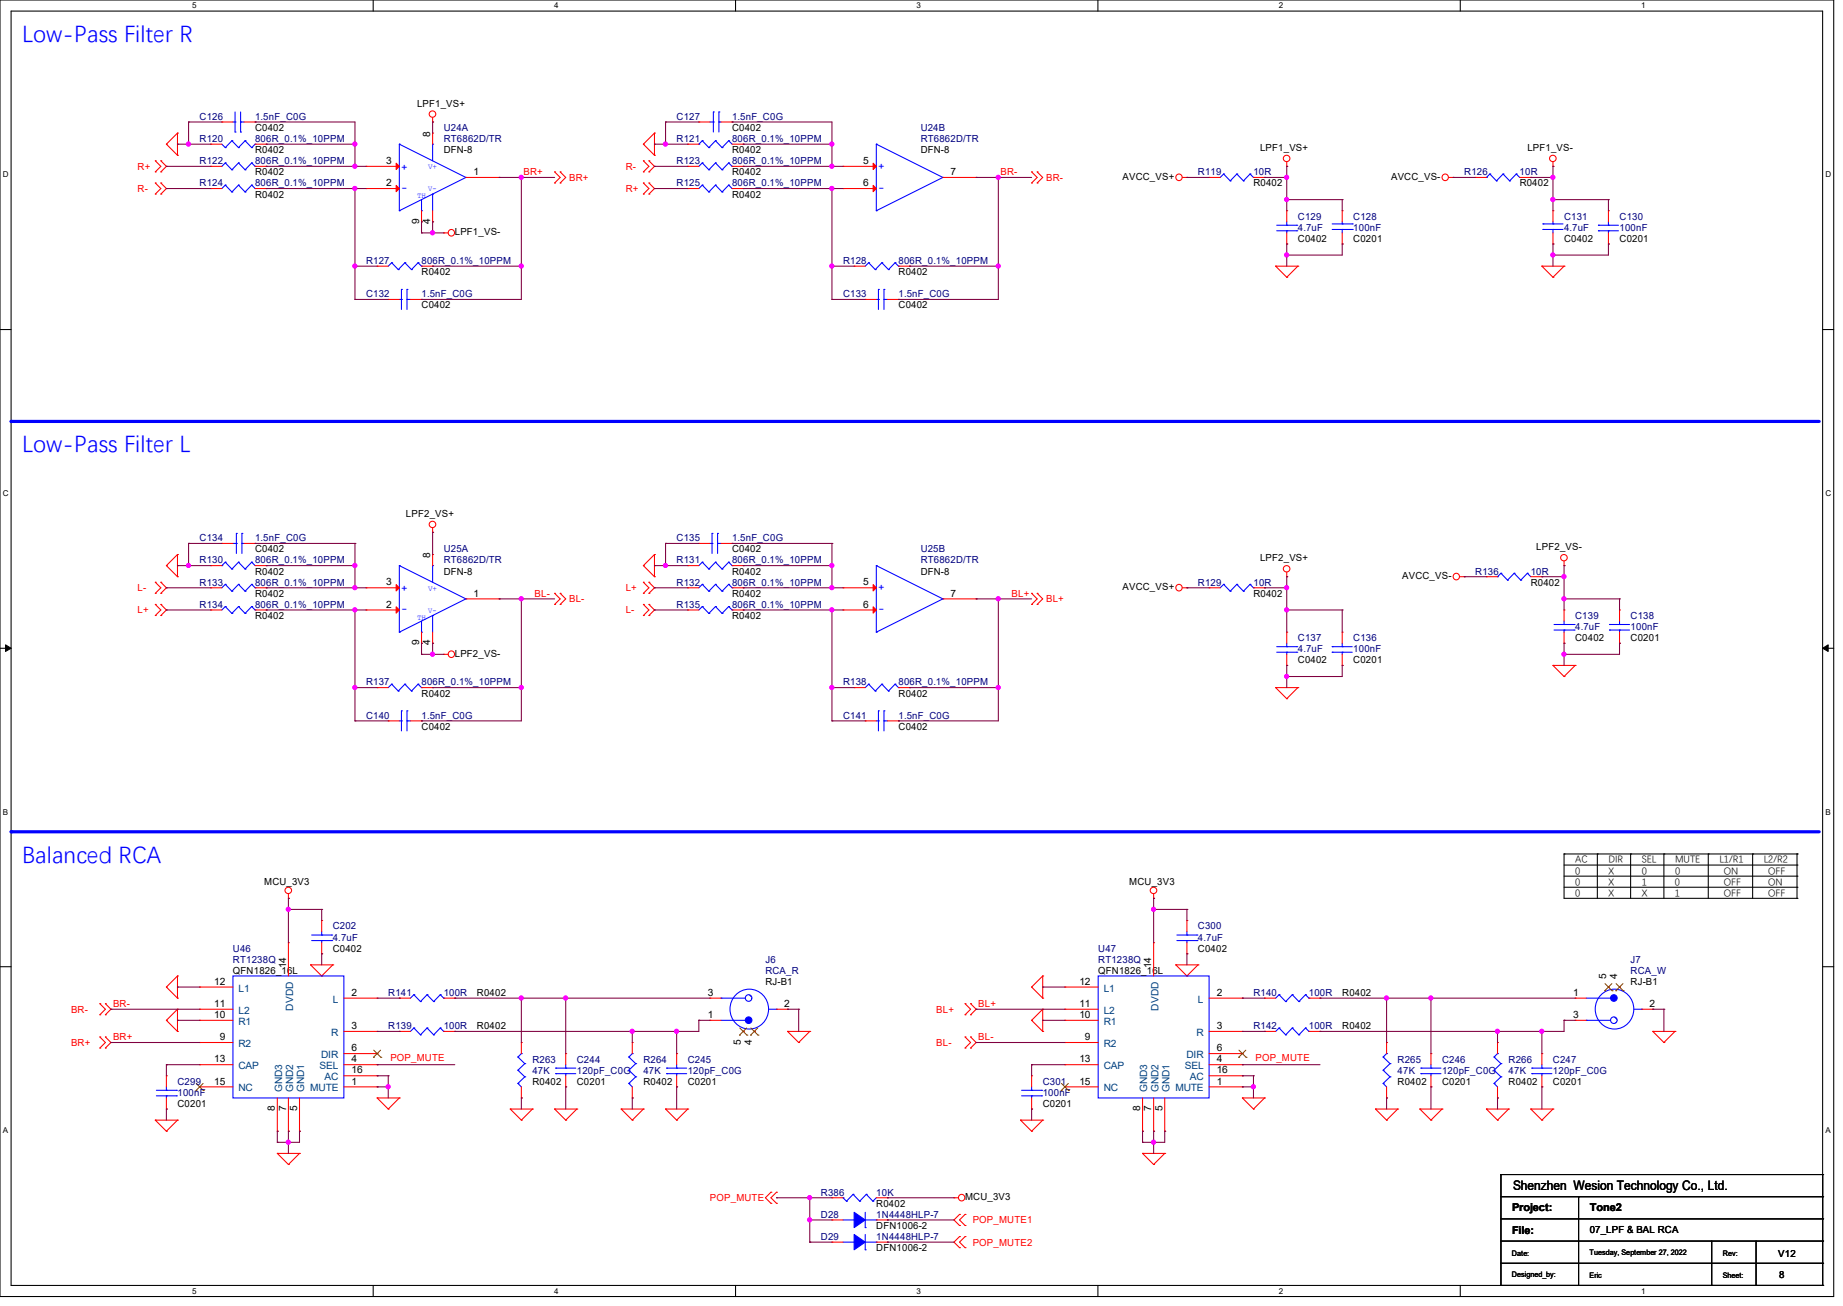
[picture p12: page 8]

0 X | | 0 0 | | ON | OFF
0 | X 0 | 1 | | OFF | ON
0 | X | X | 1 | OFF | OFF

File: Date: Shenzhen Wesion Technology Co., Ltd. Designed_by: File: Date: Shenzhen Wesion Technology Co., Ltd. Designed_by: File: Date: Shenzhen Wesion Technology Co., Ltd. Designed_by: | Rev: Sheet: Tuesday, September 27, 2022 Tone2 Eric 07_LPF & BAL RCA Rev: Sheet: Tuesday, September 27, 2022 Tone2 Eric 07_LPF & BAL RCA Rev: Sheet: Tuesday, September 27, 2022 Tone2 Eric 07_LPF & BAL RCA

# GPIO Header

# FPC Connector

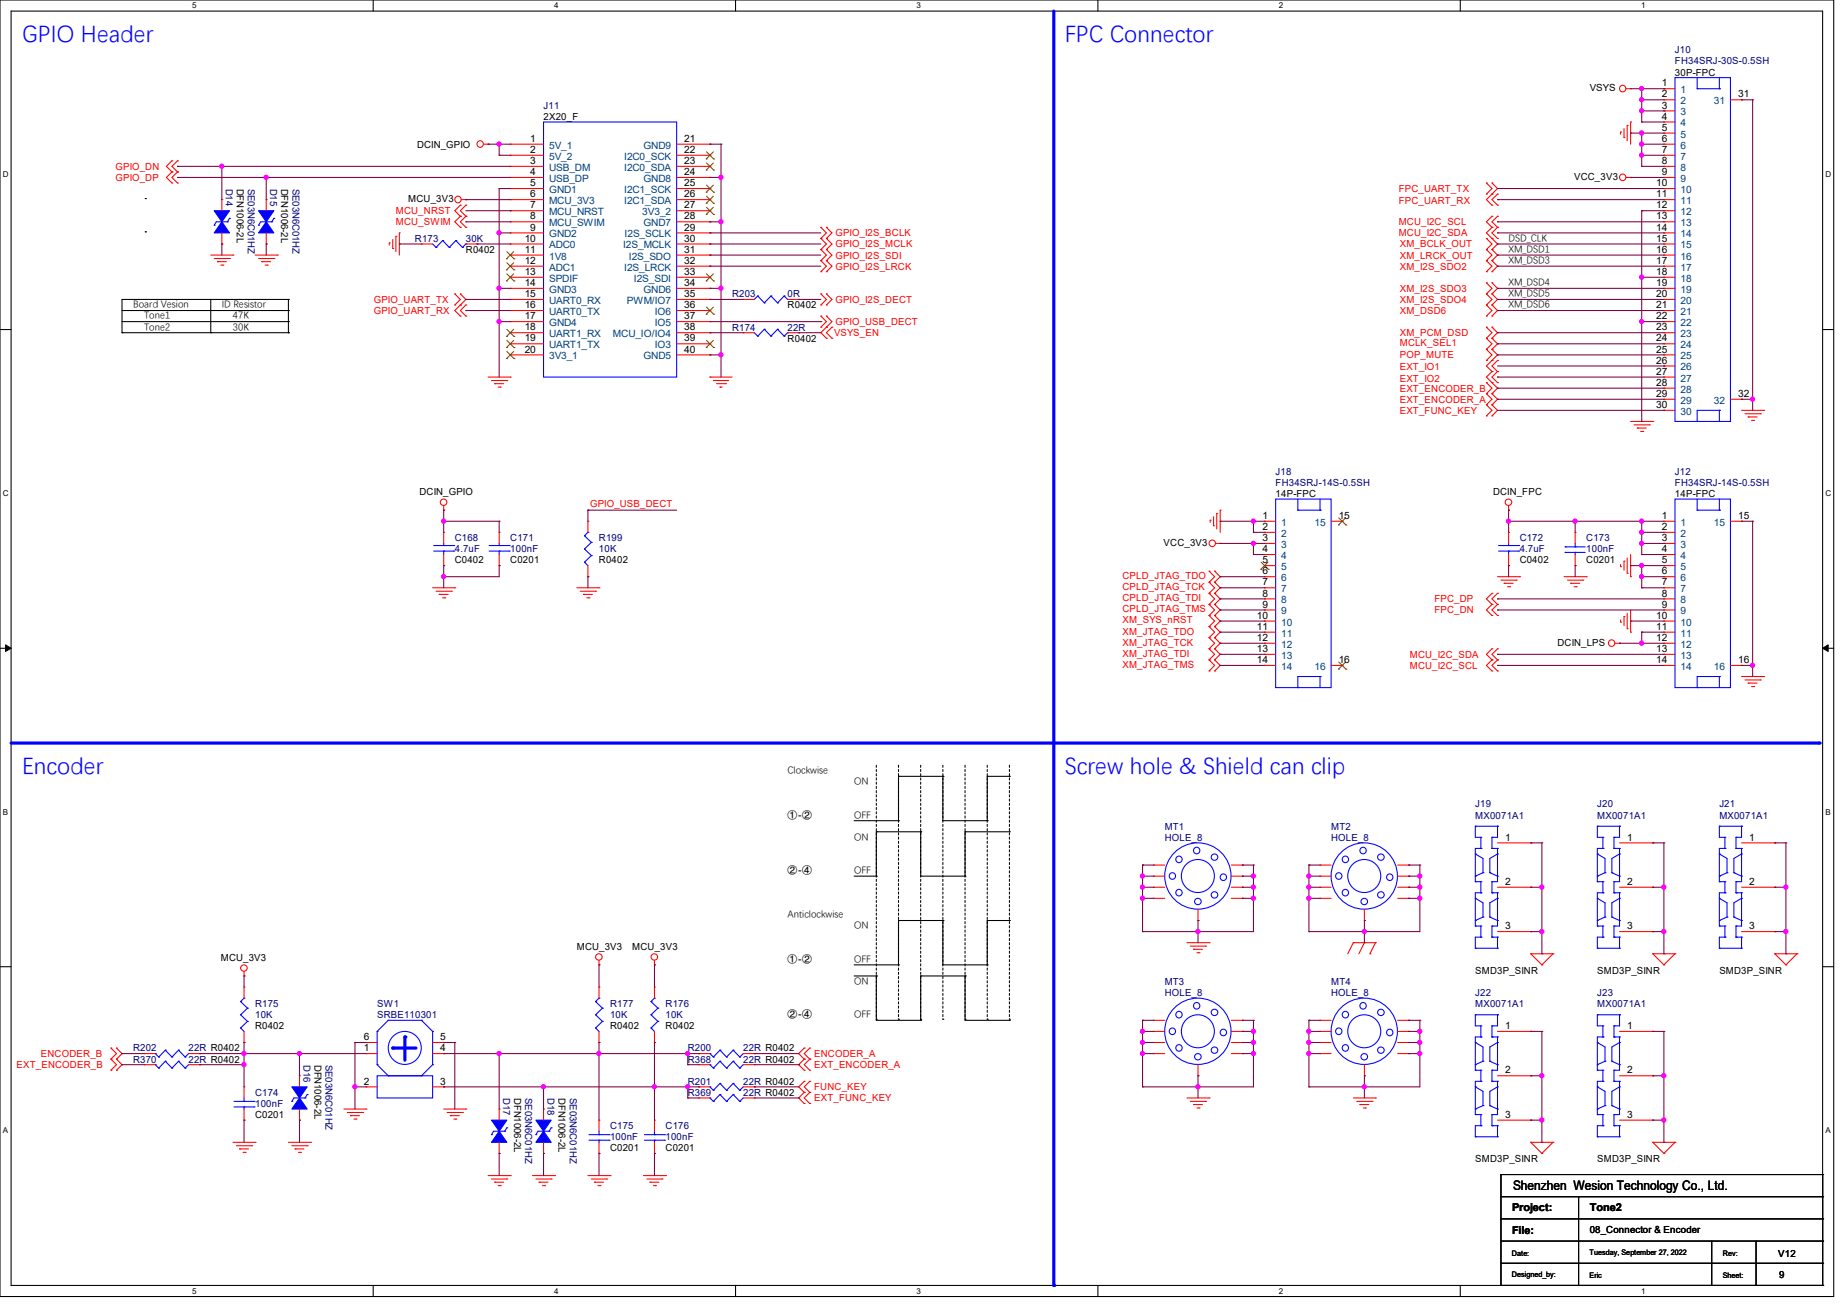
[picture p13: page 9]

Board Vesion | ID Resistor
Tone1 | 47K
Tone2 | 30K

File: Date: Shenzhen Wesion Technology Co., Ltd. Designed_by: File: Date: Shenzhen Wesion Technology Co., Ltd. Designed_by: File: Date: Shenzhen Wesion Technology Co., Ltd. Designed_by: | Rev: Sheet: Tuesday, September 27, 2022 Tone2 Eric 08_Connector & Encoder Rev: Sheet: Tuesday, September 27, 2022 Tone2 Eric 08_Connector & Encoder Rev: Sheet: Tuesday, September 27, 2022 Tone2 Eric 08_Connector & Encoder V12 V12 V12

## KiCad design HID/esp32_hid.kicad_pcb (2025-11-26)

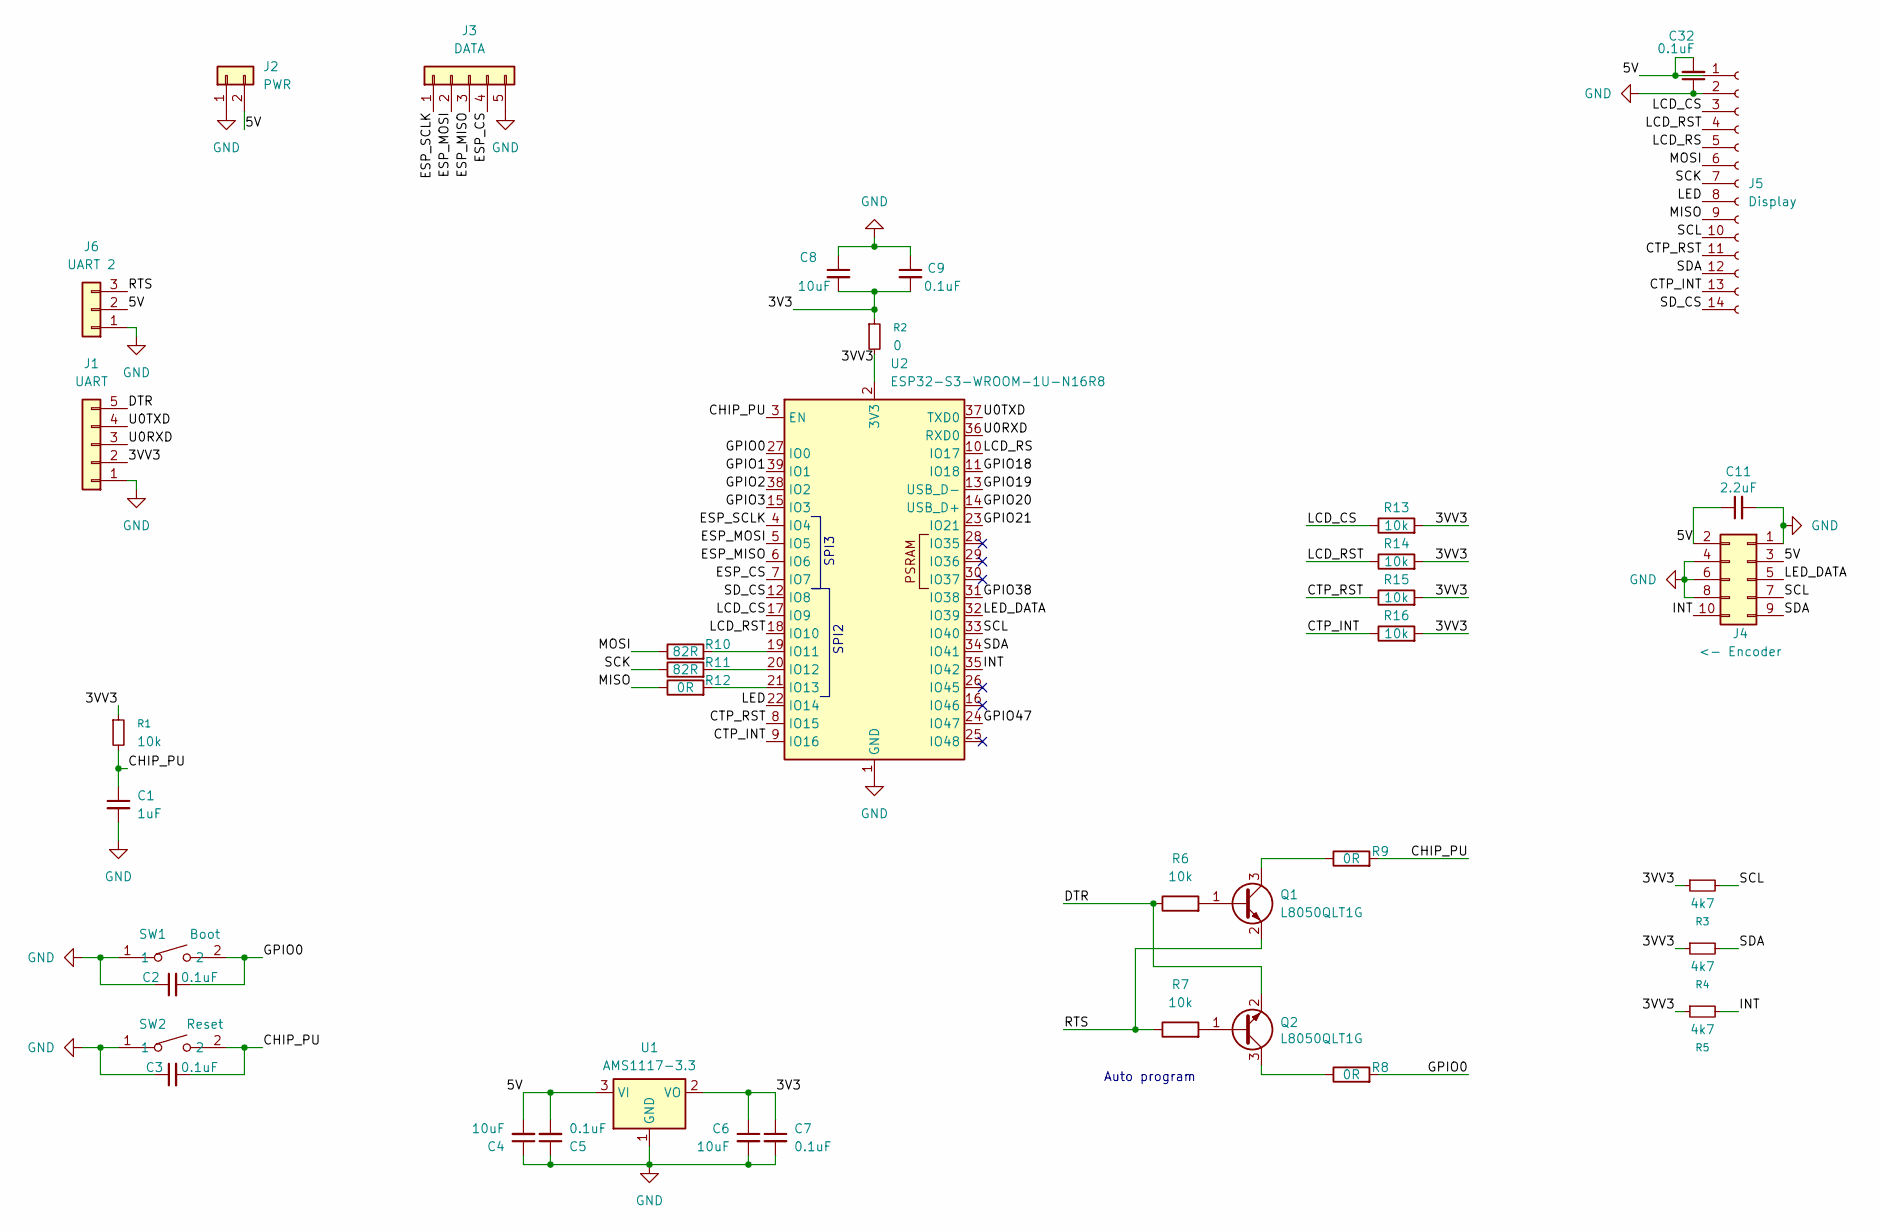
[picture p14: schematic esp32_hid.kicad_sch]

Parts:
C1: 1uF; C_0603_1608Metric
C2, C3, C5, C7, C9, C32: 0.1uF; C_0603_1608Metric
C4, C6, C8: 10uF; C_0805_2012Metric
C11: 2.2uF; C_0603_1608Metric
J1: UART; PinHeader_1x05_P2.54mm_Vertical
J2: PWR; JST_XH_B2B-XH-A_1x02_P2.50mm_Vertical
J3: DATA; JST_XH_B5B-XH-A_1x05_P2.50mm_Vertical
J4: <- Encoder; JST_PHD_B10B-PHDSS_2x05_P2.00mm_Vertical; LCSC C471519
J5: Display; PinSocket_1x14_P2.54mm_Vertical
J6: UART 2; PinHeader_1x03_P2.54mm_Vertical
Q1, Q2: L8050QLT1G; SOT-23; LCSC C49581
R1: 10k; R_0603_1608Metric
R2: 0; R_0603_1608Metric
R3, R4, R5: 4k7; R_0603_1608Metric
R6, R7, R13, R14, R15, R16: 10k; R_0603_1608Metric; LCSC C25804
R8, R9, R12: 0R; R_0603_1608Metric; LCSC C95177
R10, R11: 82R; R_0603_1608Metric; LCSC C23255
SW1: Boot; SW-SMD_L3.9-W3.0-P4.45; LCSC Part C720477
SW2: Reset; SW-SMD_L3.9-W3.0-P4.45; LCSC Part C720477
U1: AMS1117-3.3; SOT-223-3_TabPin2
U2: ESP32-S3-WROOM-1U-N16R8; ESP32-S3-WROOM-1

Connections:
/3V3: C6.1, C7.1, C8.2, C9.2, R2.1, U1.2 (VO)
/3VV3: J1.2, R1.1, R2.2, R3.1, R4.1, R5.1, R13.2, R14.2, R15.2, R16.2, U2.2 (3V3)
/5V: C4.2, C5.2, C11.1, C32.2, J2.2, J4.2, J4.3, J5.1, J6.2, U1.3 (VI)
/CHIP_PU: C1.1, C3.2, R1.2, R9.2, SW2.2, U2.3 (EN)
/CTP_INT: J5.13, R16.1, U2.9 (IO16)
/CTP_RST: J5.11, R15.1, U2.8 (IO15)
/DTR: J1.5, Q2.2 (E), R6.1
/ESP_CS: J3.4, U2.7 (IO7)
/ESP_MISO: J3.3, U2.6 (IO6)
/ESP_MOSI: J3.2, U2.5 (IO5)
/ESP_SCLK: J3.1, U2.4 (IO4)
/GPIO0: C2.2, R8.2, SW1.2, U2.27 (IO0)
/GPIO1: U2.39 (IO1)
/GPIO2: U2.38 (IO2)
/GPIO3: U2.15 (IO3)
/GPIO18: U2.11 (IO18)
/GPIO19: U2.13 (USB_D-)
/GPIO20: U2.14 (USB_D+)
/GPIO21: U2.23 (IO21)
/GPIO38: U2.31 (IO38)
/GPIO47: U2.24 (IO47)
/INT: J4.10, R5.2, U2.35 (IO42)
/LCD_CS: J5.3, R13.1, U2.17 (IO9)
/LCD_RS: J5.5, U2.10 (IO17)
/LCD_RST: J5.4, R14.1, U2.18 (IO10)
/LED: J5.8, U2.22 (IO14)
/LED_DATA: J4.5, U2.32 (IO39)
/MISO: J5.9, R12.1
/MOSI: J5.6, R10.1
/RTS: J6.3, Q1.2 (E), R7.1
/SCK: J5.7, R11.1
/SCL: J4.7, J5.10, R3.2, U2.33 (IO40)
/SDA: J4.9, J5.12, R4.2, U2.34 (IO41)
/SD_CS: J5.14, U2.12 (IO8)
/U0RXD: J1.3, U2.36 (RXD0)
/U0TXD: J1.4, U2.37 (TXD0)
GND: C1.2, C2.1, C3.1, C4.1, C5.1, C6.2, C7.2, C8.1, C9.1, C11.2, C32.1, J1.1, J2.1, J3.5, J4.1, J4.4, J4.6, J4.8, J5.2, J6.1, SW1.1, SW2.1, U1.1 (GND), U2.1 (GND), U2.40 (GND), U2.41 (GND)
unnamed: Q1.1 (B), R6.2
unnamed: Q1.3 (C), R9.1
unnamed: Q2.1 (B), R7.2
unnamed: Q2.3 (C), R8.1
unnamed: R10.2, U2.19 (IO11)
unnamed: R11.2, U2.20 (IO12)
unnamed: R12.2, U2.21 (IO13)

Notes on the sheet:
Auto program
SPI2
SPI3

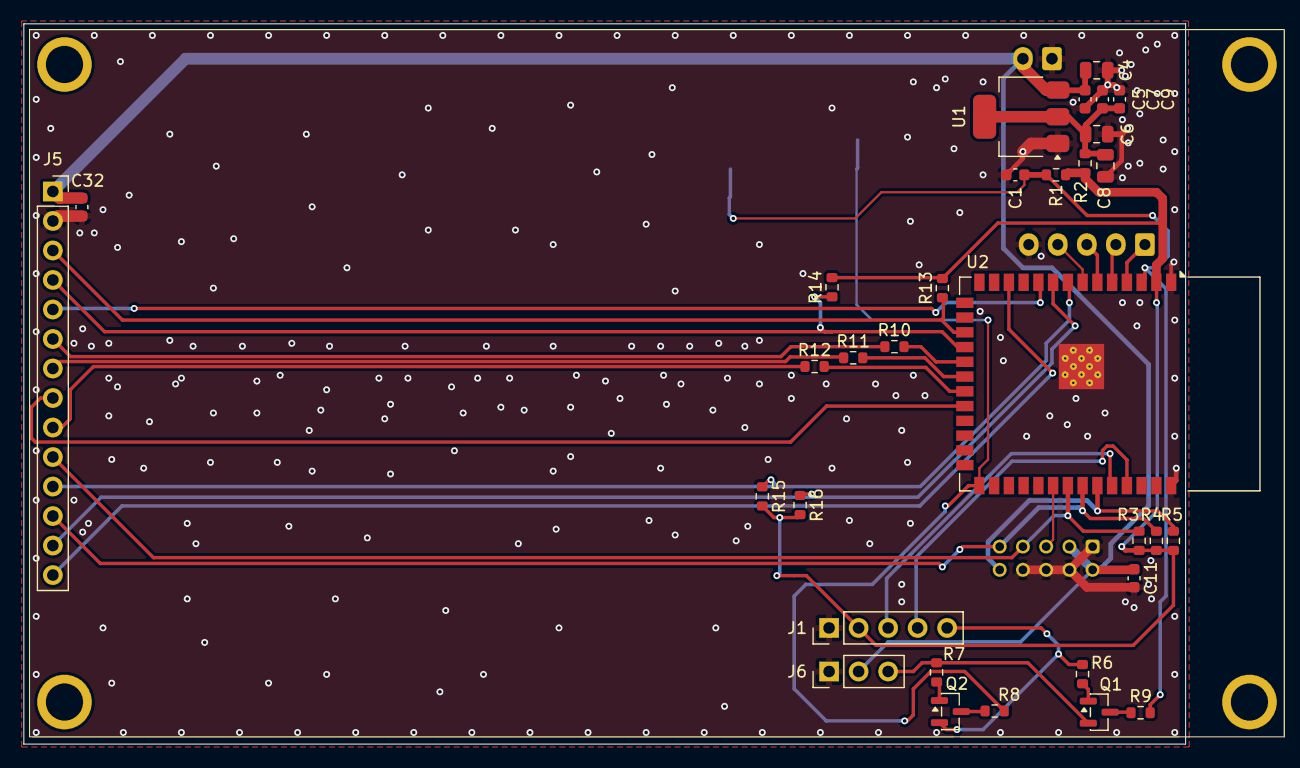
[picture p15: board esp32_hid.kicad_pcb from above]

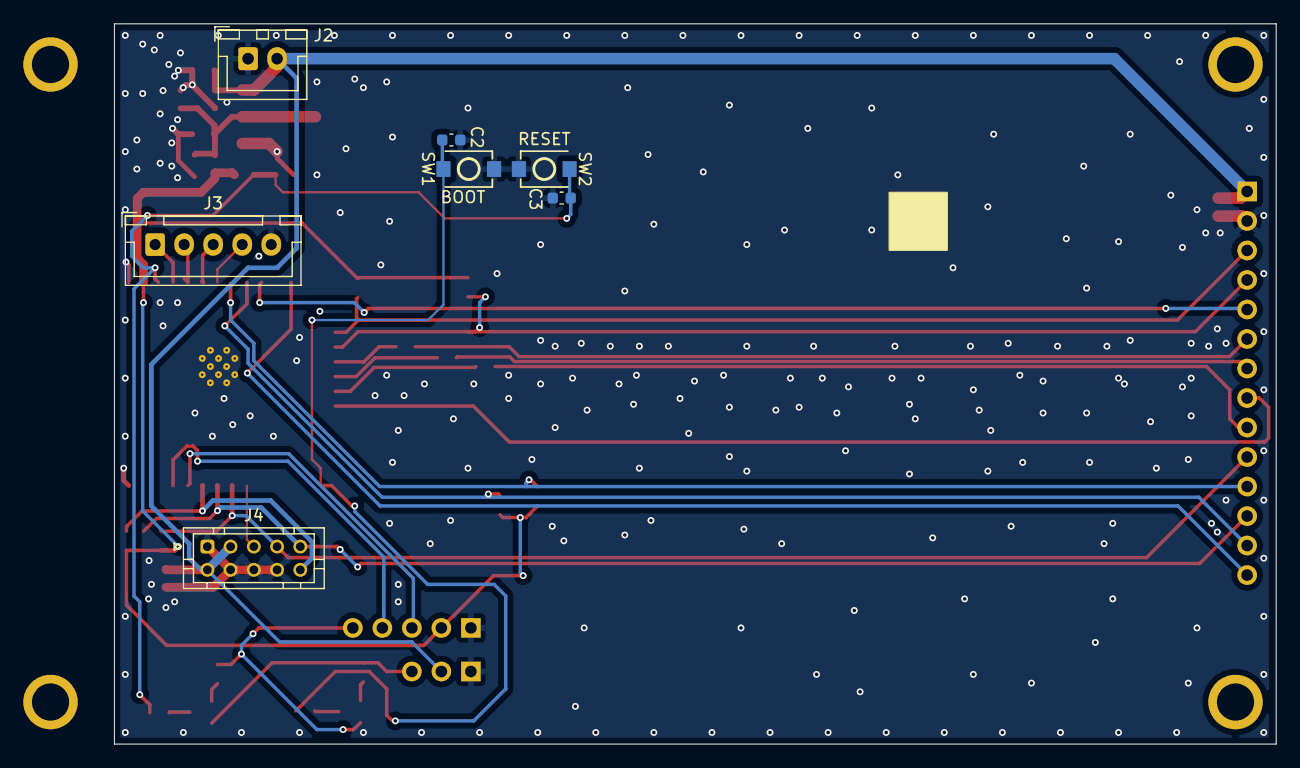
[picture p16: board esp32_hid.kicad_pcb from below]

Board: 2 copper layers, 100.0 x 62.0 mm, 39 parts (7 on the bottom side), 35 nets.

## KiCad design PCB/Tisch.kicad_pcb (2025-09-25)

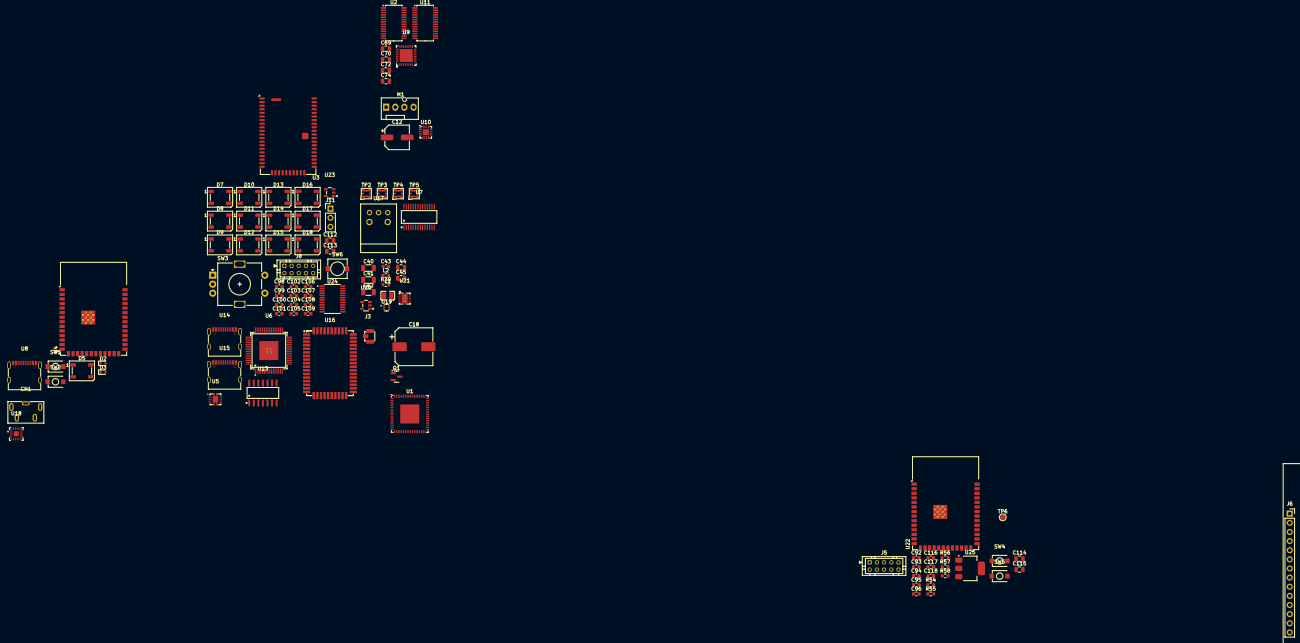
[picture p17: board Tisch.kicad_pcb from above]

Board: 2 copper layers, 102 parts (0 on the bottom side), 82 nets, no tracks yet.

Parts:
C12: 47uF; CP_Elec_6.3x5.4
C18: 100uF; CP_Elec_10x10
C40, C41, C42: 10uF; C_1206_3216Metric
C43, C118: 2.2uF; C_0603_1608Metric
C44, C45, C112, C113, C114, C115: 10uF; C_0805_2012Metric
C69, C70, C72, C74: 2.2uF; C_0805_2012Metric
C92, C94, C95, C96, C98, C99, C100, C101, C102, C103, C104, C105, C106, C107, C108, C109, C116, C117: 0.1uF; C_0603_1608Metric
C93: 1uF; C_0603_1608Metric
CN1: PJ-358H-B; AUDIO-TH_PJ-358H-B
D2, D3: LESD5D5.0CT1G; D_SOD-523
D5, D7, D8, D9, D10, D11, D12, D13, D14, D15, D16, D17, D18: WS2812B; LED_WS2812B_PLCC4_5.0x5.0mm_P3.2mm
J3: BT1 Ant; ANT-SMD_UFL-R-SMT-1-10
J5: <- Encoder; JST_PHD_B10B-PHDSS_2x05_P2.00mm_Vertical
J6: Display; PinSocket_1x14_P2.54mm_Vertical
J8: ->ESP32; JST_PHD_B10B-PHDSS_2x05_P2.00mm_Vertical
J11: OPT; PinHeader_1x03_P2.54mm_Vertical
L1: 1uH; L0806
L2: 150nH; L_0603_1608Metric
M1: P8 Max; FanPinHeader_1x04_P2.54mm_Vertical
Q1: AO3400A; SOT-23
R30: 330m; R_0603_1608Metric
R54: 10k; R_0603_1608Metric
R55: 0; R_0603_1608Metric
R56, R57, R58: 4k7; R_0603_1608Metric
SW1, SW4: Boot; SW-SMD_L3.9-W3.0-P4.45
SW2, SW5: Reset; SW-SMD_L3.9-W3.0-P4.45
SW3: EC11E15244B2; RotaryEncoder_Alps_EC11E-Switch_Vertical_H20mm
SW6: SKSUAAE010; KEY-SMD_SKSUAAE010
TP2: spdif_error; CoaxialSwitch_Hirose_MS-156C3_Horizontal
TP3: spdif_audio; CoaxialSwitch_Hirose_MS-156C3_Horizontal
TP4: spdif_fsout0; CoaxialSwitch_Hirose_MS-156C3_Horizontal
TP5: spdif_fsout1; CoaxialSwitch_Hirose_MS-156C3_Horizontal
TP6: LED_D; TestPoint_Pad_D1.5mm
U1: ADAU1451; LFCSP-72-1EP_10x10mm_P0.5mm_EP5.3x5.3mm
U2, U11: PCM5122PW; TSSOP-28_4.4x9.7mm_P0.65mm
U3: Microchip_BM83
U4: ESP32-S3-WROOM-1
U5: TS3USB221DRCR; VSON-10_L3.0-W3.0-P0.50-TL-EP_TPS62410DRCR
U6: XU208-128-TQ64-C10; TQFP-64_L10.0-W10.0-P0.50-LS12.0-BL-EP5.3
U7: DIR9001PWR; TSSOP-28_L9.7-W4.4-P0.65-LS6.4-BL
U8, U14, U15: GT-USB-7010ASV; USB-C-SMD_G-SWITCH_GT-USB-7010ASV
U9: PCM5242RHBR; VQFN-32_L5.0-W5.0-P0.50-BL-EP
U10: TMP468xxRGT; VQFN-16-1EP_3x3mm_P0.5mm_EP1.68x1.68mm
U13: CD74HC02M96; SOIC-14_L8.7-W3.9-P1.27-LS6.0-BL
U16: BTM525; SJR-BTM525
U17: PLR237/T10BK; OPTO-TH_PLR237-T10BK
U18: PCM1809IRTER; WQFN-20_L3.0-W3.0-P0.50-TL-EP1.4
U19: TPS62A02NADRL; SOT-563
U20, U23: TPS7B92033DBVR; SOT-23-5_L2.9-W1.6-P0.95-LS2.8-BR
U21: TPS7A9401DSCR; WSON-10_L3.0-W3.0-P0.50-TL-EP
U22: ESP32-S3-WROOM-1U-N16R8; ESP32-S3-WROOM-1
U24: TCA9535PWR; TSSOP-24_4.4x7.8mm_P0.65mm
U25: AMS1117-3.3; SOT-223-3_TabPin2

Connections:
+3V3: U5.10 (VCC), U13.14 (VCC)
+5V: D5.1 (VDD), L2.1, U20.1 (IN), U21.1 (IN), U21.2 (IN)
+12V: C12.1, M1.2 (+)
/ADC/Left Audio: CN1.2 (Tip), U18.1 (IN1P)
/ADC/Right Audio: CN1.5 (Ring), U18.3 (IN2P)
/DAC/LDOO: U2.26 (LDOO), U11.26 (LDOO)
/DAC/SCL: U2.12 (SCL/MC/ATT1), U9.18 (SCL/MC/ATT1), U11.12 (SCL/MC/ATT1)
/DAC/SDA: U2.11 (SDA/MOSI/ATT2), U9.17 (SDA/MOSI/ATT2), U11.11 (SDA/MOSI/ATT2)
/ESP32/CHIP_PU: SW2.2, U4.3 (EN)
/ESP32/GPIO0: SW1.2, U4.27 (IO0)
/ESP32/GPIO19: D2.2 (A2), U4.13 (USB_D-), U8.A7 (DN1), U8.B7 (DN2)
/ESP32/GPIO20: D3.2 (A2), U4.14 (USB_D+), U8.A6 (DP1), U8.B6 (DP2)
/HID/ESP32 HID/3V3: C92.2, C94.2, C115.1, C117.1, R54.1, R55.1, U25.2 (VO)
/HID/ESP32 HID/5V: C114.2, C116.2, C118.1, J5.1, J6.1, U25.3 (VI)
/HID/ESP32 HID/CHIP_PU: C93.1, C96.2, R54.2, SW5.2, U22.3 (EN)
/HID/ESP32 HID/CTP_INT: J6.13, U22.9 (IO16)
/HID/ESP32 HID/CTP_RST: J6.11, U22.8 (IO15)
/HID/ESP32 HID/GPIO0: C95.2, SW4.2
/HID/ESP32 HID/INT: J5.9, R58.2, U22.35 (IO42)
/HID/ESP32 HID/LCD_CS: J6.3, U22.17 (IO9)
/HID/ESP32 HID/LCD_RST: J6.4, U22.18 (IO10)
/HID/ESP32 HID/LED: J6.8, U22.22 (IO14)
/HID/ESP32 HID/LED_DATA: J5.3, TP6.1, U22.32 (IO39)
/HID/ESP32 HID/MISO: J6.9, U22.19 (IO11)
/HID/ESP32 HID/MOSI: J6.6, U22.20 (IO12)
/HID/ESP32 HID/SCK: J6.7, U22.21 (IO13)
/HID/ESP32 HID/SCL: J5.5, J6.10, R56.2, U22.33 (IO40)
/HID/ESP32 HID/SDA: J5.7, J6.12, R57.2, U22.34 (IO41)
/HID/ESP32 HID/SD_CS: J6.14, U22.12 (IO8)
/HID/ESP32 HID/VCC_3V3: R56.1, R57.1, R58.1
/HID/Encoder/3V3: C113.1, U23.5 (OUT)
/HID/Encoder/5V: C98.1, C99.1, C100.1, C101.1, C102.1, C103.1, C104.1, C105.1, C106.1, C107.1, C108.1, C109.1, C112.2, D7.1 (VDD), D8.1 (VDD), D9.1 (VDD), D10.1 (VDD), D11.1 (VDD), D12.1 (VDD), D13.1 (VDD), D14.1 (VDD), D15.1 (VDD), D16.1 (VDD), D17.1 (VDD), D18.1 (VDD), J8.1, U23.1 (IN)
/HID/Encoder/INT: J8.9, U24.1 (~INT)
/HID/Encoder/LED_DATA: D7.4 (DIN), J8.3
/HID/Encoder/SCL: J8.5, U24.22 (SCL)
/HID/Encoder/SDA: J8.7, U24.23 (SDA)
/HID/Encoder/back_sw: SW6.1, U24.7 (P03)
/HID/Encoder/rot_a: SW3.A, U24.4 (P00)
/HID/Encoder/rot_b: SW3.B, U24.5 (P01)
/HID/Encoder/rot_sw: SW3.S1, U24.6 (P02)
/QCC5125/RF_ANT_50R: J3.1 (In), U16.46 (RF)
/SPdif/SPDIF: U7.20 (RXIN), U17.3 (VOUT)
/USB audio/1D+: U5.1 (1D+), U14.A6 (DP1), U14.B6 (DP2)
/USB audio/1D-: U5.2 (1D-), U14.A7 (DN1), U14.B7 (DN2)
/USB audio/2D+: U5.3 (2D+), U15.A6 (DP1), U15.B6 (DP2)
/USB audio/2D-: U5.4 (2D-), U15.A7 (DN1), U15.B7 (DN2)
AVDD_3V3: C72.1, U2.8 (AVDD), U7.24 (VCC), U9.5 (CPVDD), U9.14 (AVDD), U11.8 (AVDD), U17.1 (VCC), U18.16 (AVDD), U21.8 (SNS), U21.9 (OUT), U21.10 (OUT)
DVDD_3V3: C40.1, C41.1, C42.1, L1.2, U2.18 (MODE2/MS), U2.28 (DVDD), U3.23 (BAT_IN), U9.22 (ADR2/GPIO2/GPO), U9.24 (MODE2/MS), U11.16 (ADR2/GPIO2/DOUT), U11.18 (MODE2/MS), U11.24 (ADR1/MISO/FMT), U11.28 (DVDD), U19.6 (OUT)
GND: C12.2, C18.2, C40.2, C41.2, C42.2, C43.2, C44.2, C45.2, C70.1, C72.2, C74.1, C92.1, C93.2, C94.1, C95.1, C96.1, C98.2, C99.2, C100.2, C101.2, C102.2, C103.2, C104.2, C105.2, C106.2, C107.2, C108.2, C109.2, C112.1, C113.2, C114.1, C115.2, C116.1, C117.2, C118.2, CN1.3 (TSW), D2.1 (A1), D3.1 (A1), D5.3 (VSS), D7.3 (VSS), D8.3 (VSS), D9.3 (VSS), D10.3 (VSS), D11.3 (VSS), D12.3 (VSS), D13.3 (VSS), D14.3 (VSS), D15.3 (VSS), D16.3 (VSS), D17.3 (VSS), D18.3 (VSS), J3.2 (Ext), J5.2, J5.4, J5.6, J5.8, J5.10, J6.2, J8.2, J8.4, J8.6, J8.8, J8.10, M1.1 (-), Q1.2 (S), SW1.1, SW2.1, SW3.C, SW3.MP, SW3.S2, SW4.1, SW5.1, SW6.2, U2.3 (CPGND), U2.9 (AGND), U2.16 (ADR2/GPIO2/DOUT), U2.17 (MODE1), U2.24 (ADR1/MISO/FMT), U2.27 (DGND), U3.16 (GND), U3.50 (GND), U3.56 (GND), U3.57 (GND), U4.1 (GND), U4.40 (GND), U4.41 (GND), U5.5 (GND), U5.11, U7.6 (DGND), U7.13 (PSCK0), U7.14 (PSCK1), U7.19 (RSV), U7.23 (AGND), U7.28 (CKSEL), U8.1 (SHELL), U8.2 (SHELL), U8.3 (SHELL), U8.4 (SHELL), U9.3 (DGND), U9.7 (CPGND), U9.15 (AGND), U9.23 (MODE1), U9.32 (ADR1/MISO/FMT), U9.33 (PAD), U10.8 (GND), U10.9 (ADD), U10.17 (GND), U11.3 (CPGND), U11.9 (AGND), U11.17 (MODE1), U11.27 (DGND), U13.5 (2A), U13.6 (2B), U13.7 (GND), U13.8 (3A), U13.9 (3B), U13.11 (4A), U13.12 (4B), U16.15 (GND), U16.21 (GND), U16.38 (GND), U16.44 (GND), U16.45 (GND), U16.47 (GND), U17.2 (GND), U18.2 (IN1M), U18.4 (IN2M), U18.5 (VSS), U18.10 (VSS), U18.11 (MD1), U18.12 (MD0), U18.13 (MSZ), U18.15 (VSS), U18.19 (FMT0), U18.20 (VSS), U18.21 (EP), U19.1 (GND), U20.2 (GND), U21.4 (PG), U21.6 (GND), U21.11 (EP), U22.1 (GND), U22.40 (GND), U22.41 (GND), U23.2 (GND), U24.2 (A1), U24.3 (A2), U24.12 (GND), U24.21 (A0), U25.1 (GND)
IOVDD_3V3: C70.2, U2.1 (CPVDD), U7.5 (VDD), U9.4 (DVDD), U10.14 (V+), U11.1 (CPVDD), U16.7 (VBAT_SENSE), U16.14 (VBAT), U16.23 (VDD_PADS1), U16.24 (VDD_PADS3_7), U18.9 (IOVDD), U20.5 (OUT)
unnamed: C44.1, R30.2
unnamed: D7.2 (DOUT), D8.4 (DIN)
unnamed: D8.2 (DOUT), D9.4 (DIN)
unnamed: D9.2 (DOUT), D10.4 (DIN)
unnamed: D10.2 (DOUT), D11.4 (DIN)
unnamed: D11.2 (DOUT), D12.4 (DIN)
unnamed: D12.2 (DOUT), D13.4 (DIN)
unnamed: D13.2 (DOUT), D14.4 (DIN)
unnamed: D14.2 (DOUT), D15.4 (DIN)
unnamed: D15.2 (DOUT), D16.4 (DIN)
unnamed: D16.2 (DOUT), D17.4 (DIN)
unnamed: D17.2 (DOUT), D18.4 (DIN)
unnamed: J11.1, U24.8 (P04)
unnamed: J11.2, U24.9 (P05)
unnamed: J11.3, U24.10 (P06)
unnamed: U1.1 (DGND), U1.17 (DGND), U1.19 (DGND), U1.25 (DGND), U1.36 (DGND), U1.37 (DGND), U1.54 (DGND), U1.55 (DGND), U1.72 (DGND)
unnamed: U1.20 (DVDD), U1.35 (DVDD), U1.53 (DVDD), U1.71 (DVDD)
unnamed: U1.2 (IOVDD), U1.18 (IOVDD), U1.38 (IOVDD), U1.56 (IOVDD)
unnamed: C69.1, U9.8 (CAPM)
unnamed: C69.2, U9.6 (CAPP)
unnamed: C74.2, U9.9 (VNEG)
unnamed: U10.1 (D6+), U10.2 (D5+), U10.3 (D4+), U10.4 (D3+), U10.5 (D2+), U10.6 (D1+), U10.7 (D-), U10.15 (D8+), U10.16 (D7+)
unnamed: U5.9 (S), U13.3 (1B)
unnamed: U5.6 (~OE), U13.1 (1Y)
unnamed: U14.3 (SHELL), U14.4 (SHELL)
unnamed: U14.1 (SHELL), U14.2 (SHELL)
unnamed: U15.3 (SHELL), U15.4 (SHELL)
unnamed: U15.1 (SHELL), U15.2 (SHELL)
unnamed: C43.1, C45.1, L2.2, R30.1, U19.3 (VIN), U19.4 (EN)
unnamed: L1.1, U19.2 (SW)
unnamed: R55.2, U22.2 (3V3)
VBUS: U16.10 (VCHG), U16.11 (VCHG_SENSE)

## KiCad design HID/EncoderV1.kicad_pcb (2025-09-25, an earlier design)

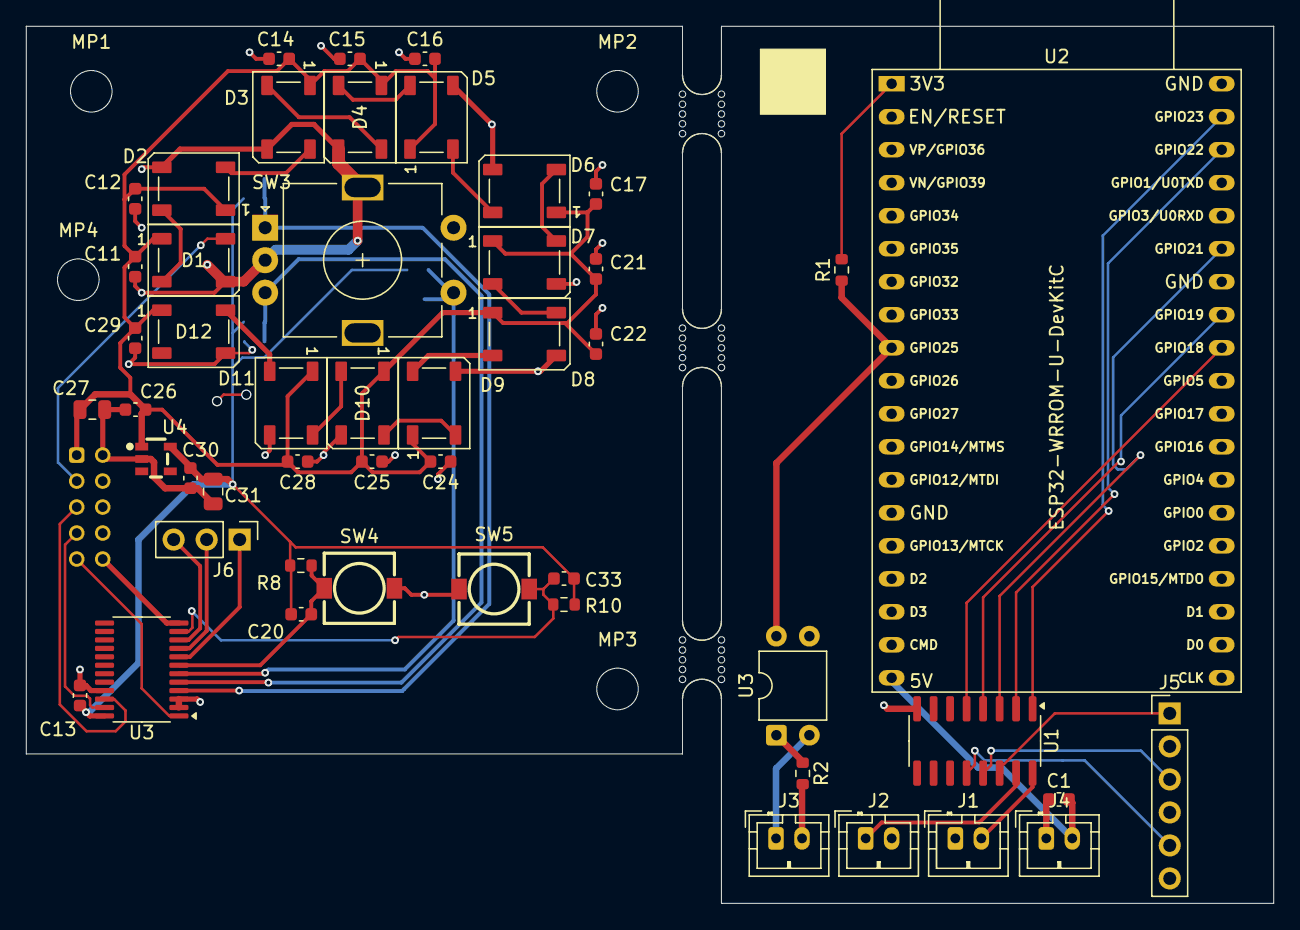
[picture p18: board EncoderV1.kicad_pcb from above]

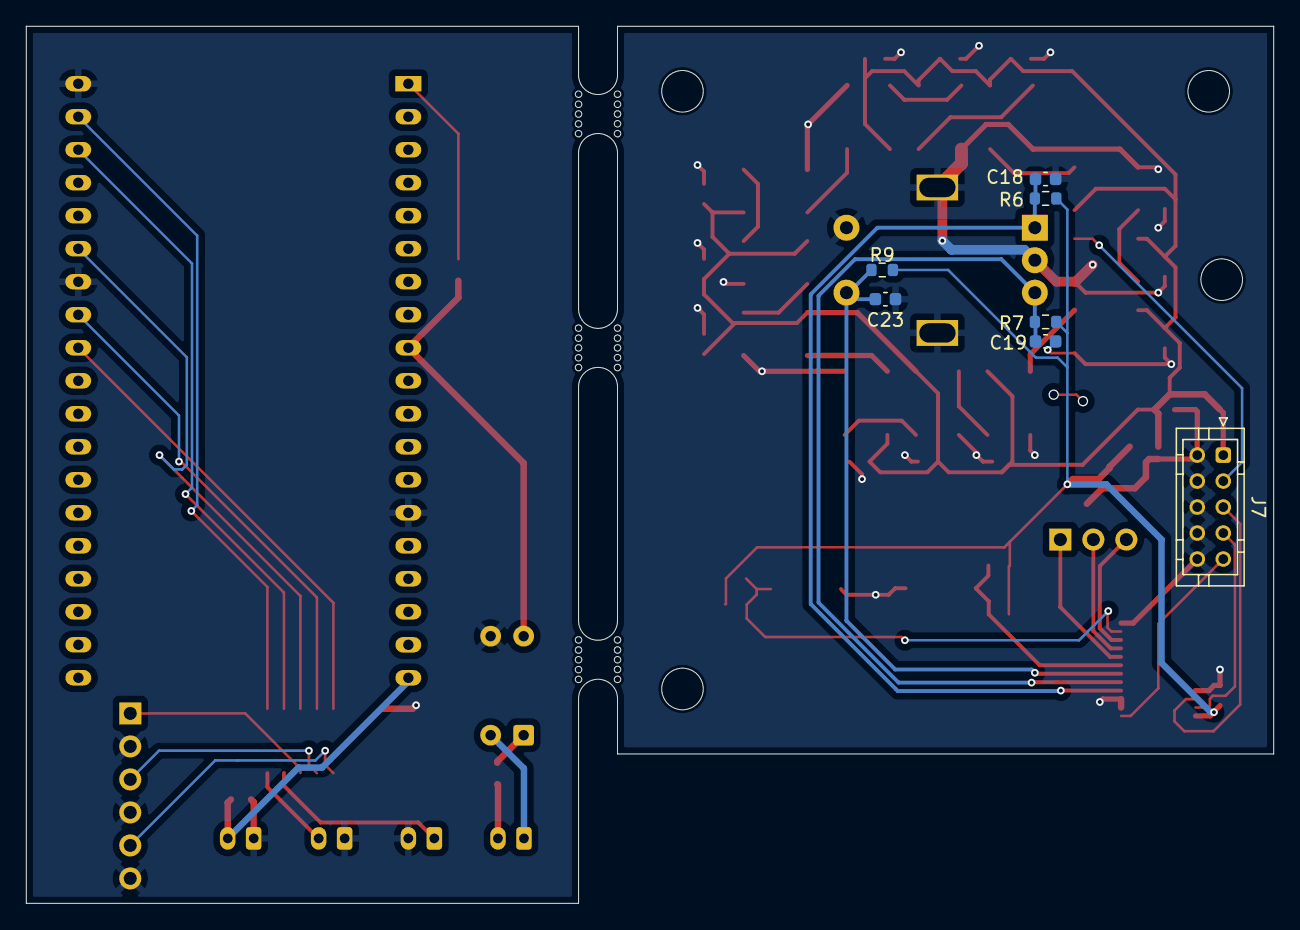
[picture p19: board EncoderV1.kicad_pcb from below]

Board: 2 copper layers, 96.0 x 67.5 mm, 64 parts (7 on the bottom side), 42 nets.

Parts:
C1: 10uF; C_0603_1608Metric
C11, C12, C13, C14, C15, C16, C17, C18, C19, C20, C21, C22, C23, C24, C25, C26, C28, C29, C30, C33: 0.1uF; C_0603_1608Metric
C27, C31: 10uF; C_0805_2012Metric
D1, D2, D3, D4, D5, D6, D7, D8, D9, D10, D11, D12: WS2812B; LED_WS2812B_PLCC4_5.0x5.0mm_P3.2mm
J1: POWER_BTN; JST_PH_B2B-PH-K_1x02_P2.00mm_Vertical
J2: AUX1; JST_PH_B2B-PH-K_1x02_P2.00mm_Vertical
J3: POWER_LED; JST_PH_B2B-PH-K_1x02_P2.00mm_Vertical
J4: POWER; JST_PH_B2B-PH-K_1x02_P2.00mm_Vertical
J5: OPT; PinHeader_1x06_P2.54mm_Vertical
J6: OPT; PinHeader_1x03_P2.54mm_Vertical
J7: ->ESP32; JST_PHD_B10B-PHDSS_2x05_P2.00mm_Vertical
MP1, MP2, MP3, MP4: MountingHole_3.2mm_M3_ISO7380
R1: 4k7; R_0603_1608Metric
R2: 220R; R_0603_1608Metric
R6, R7, R8, R9, R10: 10k; R_0603_1608Metric
SW3: EC11E15244B2; RotaryEncoder_Alps_EC11E-Switch_Vertical_H20mm
SW4, SW5: SKSUAAE010; KEY-SMD_SKSUAAE010
U1: ULN2003A; SOIC-16_3.9x9.9mm_P1.27mm
U2: ESP32-WRROM-U-DevKitC; ESP32-DevKitC
U3: PC817; DIP-4_W7.62mm
U3#2: TCA9535PWR; TSSOP-24_4.4x7.8mm_P0.65mm
U4: TPS7B92033DBVR; SOT-23-5_L2.9-W1.6-P0.95-LS2.8-BR
mouse-bite-3mm-slot, mouse-bite-3mm-slot#2, mouse-bite-3mm-slot#3: VAL**; mouse-bite-3mm-slot

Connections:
+3V3: R1.2, U2.1 (3V3)
+5V: C1.2, J4.2, U2.19 (5V)
/Encoder/3V3: C13.2, C20.1, C30.1, C31.1, C33.1, R6.1, R7.1, R8.1, R9.1, R10.1, U3#2.24 (VCC), U4.5 (OUT)
/Encoder/5V: C11.1, C12.1, C14.1, C15.1, C16.1, C17.1, C21.1, C22.1, C24.1, C25.1, C26.1, C27.2, C28.1, C29.1, D1.1 (VDD), D2.1 (VDD), D3.1 (VDD), D4.1 (VDD), D5.1 (VDD), D6.1 (VDD), D7.1 (VDD), D8.1 (VDD), D9.1 (VDD), D10.1 (VDD), D11.1 (VDD), D12.1 (VDD), J7.1, U4.1 (IN)
/Encoder/INT: J7.9, U3#2.1 (~INT)
/Encoder/LED_DATA: D1.4 (DIN), J7.3
/Encoder/SCL: J7.5, U3#2.22 (SCL)
/Encoder/SDA: J7.7, U3#2.23 (SDA)
/Encoder/back_sw: C20.2, R8.2, SW4.1, U3#2.7 (P03)
/Encoder/rot_a: C18.2, R6.2, SW3.A, U3#2.4 (P00)
/Encoder/rot_b: C19.2, R7.2, SW3.B, U3#2.5 (P01)
/Encoder/rot_sw: C23.2, R9.2, SW3.S1, U3#2.6 (P02)
/Encoder/sw_2: C33.2, R10.2, SW5.1, U3#2.11 (P07)
/IN1: U1.1 (I1), U2.37 (GPIO23)
/IN2: U1.2 (I2), U2.36 (GPIO22)
/IN3: U1.3 (I3), U2.33 (GPIO21)
/IN4: U1.4 (I4), U2.31 (GPIO19)
/IN5: U1.5 (I5), U2.30 (GPIO18)
GND: C1.1, C11.2, C12.2, C13.1, C14.2, C15.2, C16.2, C17.2, C18.1, C19.1, C21.2, C22.2, C23.1, C24.2, C25.2, C26.2, C27.1, C28.2, C29.2, C30.2, C31.2, D1.3 (VSS), D2.3 (VSS), D3.3 (VSS), D4.3 (VSS), D5.3 (VSS), D6.3 (VSS), D7.3 (VSS), D8.3 (VSS), D9.3 (VSS), D10.3 (VSS), D11.3 (VSS), D12.3 (VSS), J1.1, J2.2, J4.1, J5.2, J5.4, J5.6, J7.2, J7.4, J7.6, J7.8, J7.10, SW3.C, SW3.MP, SW3.S2, SW4.2, SW5.2, U1.8 (GND), U2.14 (GND), U2.32 (GND), U2.38 (GND), U3.3, U3#2.2 (A1), U3#2.3 (A2), U3#2.12 (GND), U3#2.21 (A0), U4.2 (GND)
unnamed: D1.2 (DOUT), D2.4 (DIN)
unnamed: D2.2 (DOUT), D3.4 (DIN)
unnamed: D3.2 (DOUT), D4.4 (DIN)
unnamed: D4.2 (DOUT), D5.4 (DIN)
unnamed: D5.2 (DOUT), D6.4 (DIN)
unnamed: D6.2 (DOUT), D7.4 (DIN)
unnamed: D7.2 (DOUT), D8.4 (DIN)
unnamed: D8.2 (DOUT), D9.4 (DIN)
unnamed: D9.2 (DOUT), D10.4 (DIN)
unnamed: D10.2 (DOUT), D11.4 (DIN)
unnamed: D11.2 (DOUT), D12.4 (DIN)
unnamed: J1.2, U1.16 (O1)
unnamed: J2.1, U1.15 (O2)
unnamed: J3.1, U3.2
unnamed: J3.2, R2.2
unnamed: J5.1, U1.14 (O3)
unnamed: J5.3, U1.13 (O4)
unnamed: J5.5, U1.12 (O5)
unnamed: J6.1, U3#2.8 (P04)
unnamed: J6.2, U3#2.9 (P05)
unnamed: J6.3, U3#2.10 (P06)
unnamed: R2.1, U3.1
unnamed: R1.1, U2.9 (DAC_1/ADC2_CH8/GPIO25), U3.4

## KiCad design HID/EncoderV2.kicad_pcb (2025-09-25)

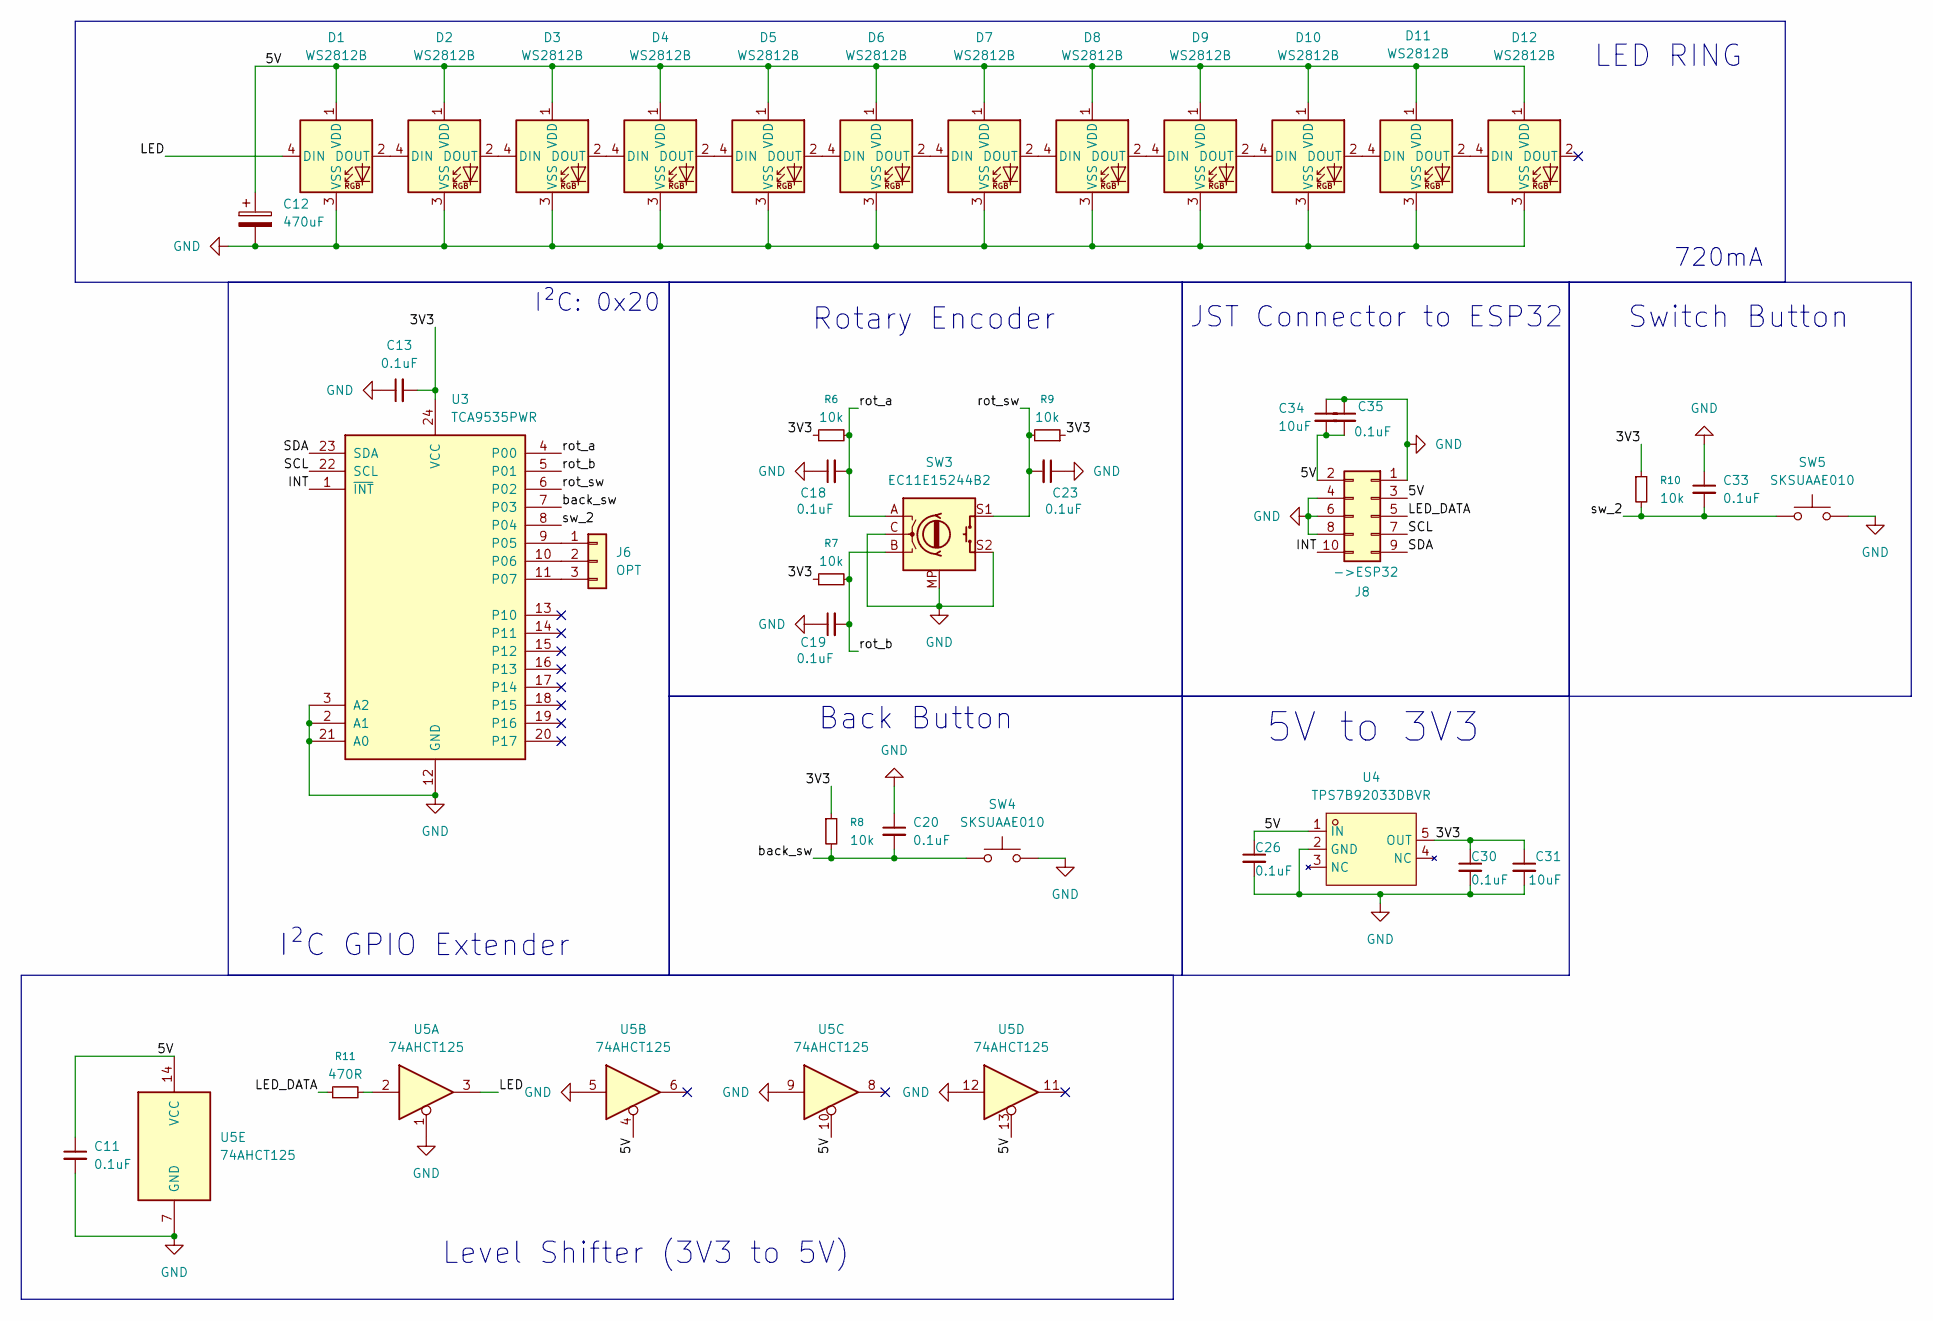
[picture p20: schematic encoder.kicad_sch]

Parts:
C11, C13, C18, C19, C20, C23, C26, C30, C33, C35: 0.1uF; C_0603_1608Metric
C12: 470uF; CP_Elec_6.3x7.7
C31, C34: 10uF; C_0805_2012Metric
D1, D2, D3, D4, D5, D6, D7, D8, D9, D10, D12: WS2812B; LED_WS2812B_PLCC4_5.0x5.0mm_P3.2mm; LCSC C2874885
D11: WS2812B; LED_WS2812B_PLCC4_5.0x5.0mm_P3.2mm
J6: OPT; PinHeader_1x03_P2.54mm_Vertical
J8: ->ESP32; JST_PHD_B10B-PHDSS_2x05_P2.00mm_Vertical; LCSC C471519
R6, R7, R8, R9, R10: 10k; R_0603_1608Metric
R11: 470R; R_0603_1608Metric
SW3: EC11E15244B2; RotaryEncoder_Alps_EC11E-Switch_Vertical_H20mm
SW4, SW5: SKSUAAE010; KEY-SMD_SKSUAAE010
U3: TCA9535PWR; TSSOP-24_4.4x7.8mm_P0.65mm
U4: TPS7B92033DBVR; SOT-23-5_L2.9-W1.6-P0.95-LS2.8-BR; LCSC Part C32353919
U5: 74AHCT125; VQFN-14_L3.5-W3.5-P0.50-BL-EP; LCSC C2675532

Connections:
/Encoder/3V3: C13.2, C30.1, C31.1, R6.1, R7.1, R8.1, R9.1, R10.1, U3.24 (VCC), U4.5 (OUT)
/Encoder/5V: C11.1, C12.1, C26.1, C34.2, C35.2, D1.1 (VDD), D2.1 (VDD), D3.1 (VDD), D4.1 (VDD), D5.1 (VDD), D6.1 (VDD), D7.1 (VDD), D8.1 (VDD), D9.1 (VDD), D10.1 (VDD), D11.1 (VDD), D12.1 (VDD), J8.2, J8.3, U4.1 (IN), U5.4, U5.10, U5.13, U5.14 (VCC)
/Encoder/INT: J8.10, U3.1 (~INT)
/Encoder/LED: D1.4 (DIN), U5.3
/Encoder/LED_DATA: J8.5, R11.1
/Encoder/SCL: J8.7, U3.22 (SCL)
/Encoder/SDA: J8.9, U3.23 (SDA)
/Encoder/back_sw: C20.2, R8.2, SW4.1, U3.7 (P03)
/Encoder/rot_a: C18.2, R6.2, SW3.A, U3.4 (P00)
/Encoder/rot_b: C19.2, R7.2, SW3.B, U3.5 (P01)
/Encoder/rot_sw: C23.2, R9.2, SW3.S1, U3.6 (P02)
/Encoder/sw_2: C33.2, R10.2, SW5.1, U3.8 (P04)
GND: C11.2, C12.2, C13.1, C18.1, C19.1, C20.1, C23.1, C26.2, C30.2, C31.2, C33.1, C34.1, C35.1, D1.3 (VSS), D2.3 (VSS), D3.3 (VSS), D4.3 (VSS), D5.3 (VSS), D6.3 (VSS), D7.3 (VSS), D8.3 (VSS), D9.3 (VSS), D10.3 (VSS), D11.3 (VSS), D12.3 (VSS), J8.1, J8.4, J8.6, J8.8, SW3.C, SW3.MP, SW3.S2, SW4.2, SW5.2, U3.2 (A1), U3.3 (A2), U3.12 (GND), U3.21 (A0), U4.2 (GND), U5.1, U5.5, U5.7 (GND), U5.9, U5.12; also elsewhere on the board
unnamed: D1.2 (DOUT), D2.4 (DIN)
unnamed: D2.2 (DOUT), D3.4 (DIN)
unnamed: D3.2 (DOUT), D4.4 (DIN)
unnamed: D4.2 (DOUT), D5.4 (DIN)
unnamed: D5.2 (DOUT), D6.4 (DIN)
unnamed: D6.2 (DOUT), D7.4 (DIN)
unnamed: D7.2 (DOUT), D8.4 (DIN)
unnamed: D8.2 (DOUT), D9.4 (DIN)
unnamed: D9.2 (DOUT), D10.4 (DIN)
unnamed: D10.2 (DOUT), D11.4 (DIN)
unnamed: D11.2 (DOUT), D12.4 (DIN)
unnamed: J6.1, U3.9 (P05)
unnamed: J6.2, U3.10 (P06)
unnamed: J6.3, U3.11 (P07)
unnamed: R11.2, U5.2

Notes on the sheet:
I²C: 0x20
JST Connector to ESP32
LED RING
I²C GPIO Extender
Rotary Encoder
720mA
Back Button
5V to 3V3
Switch Button
Level Shifter (3V3 to 5V)

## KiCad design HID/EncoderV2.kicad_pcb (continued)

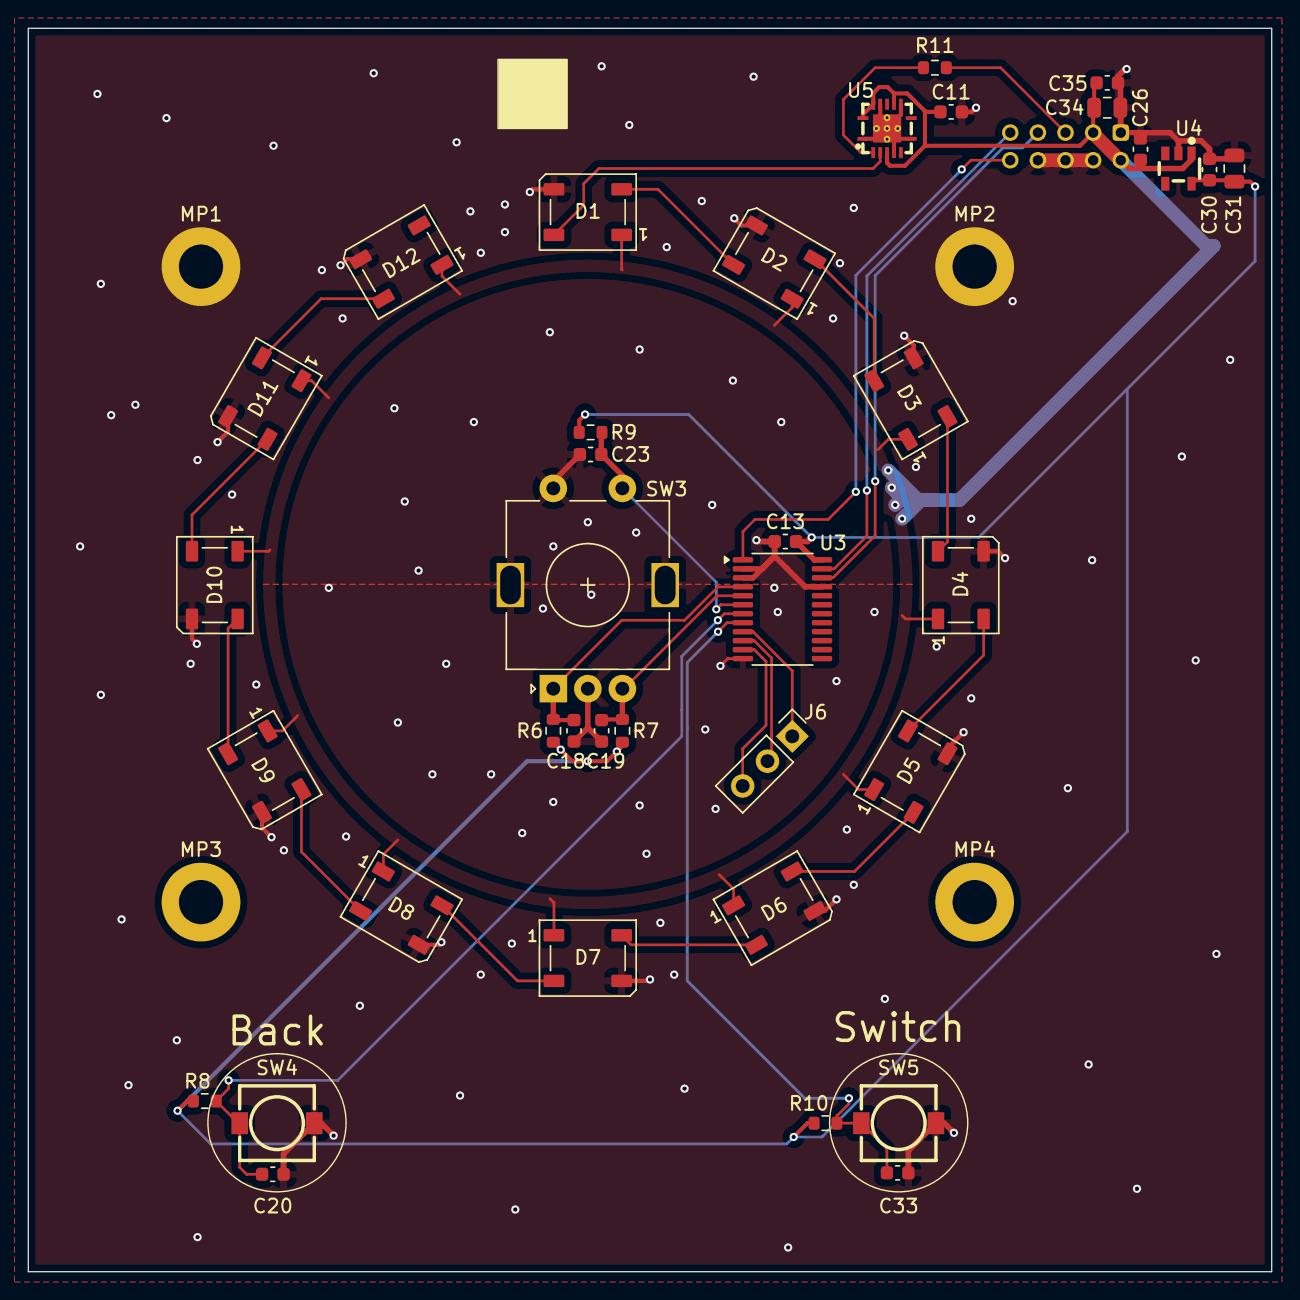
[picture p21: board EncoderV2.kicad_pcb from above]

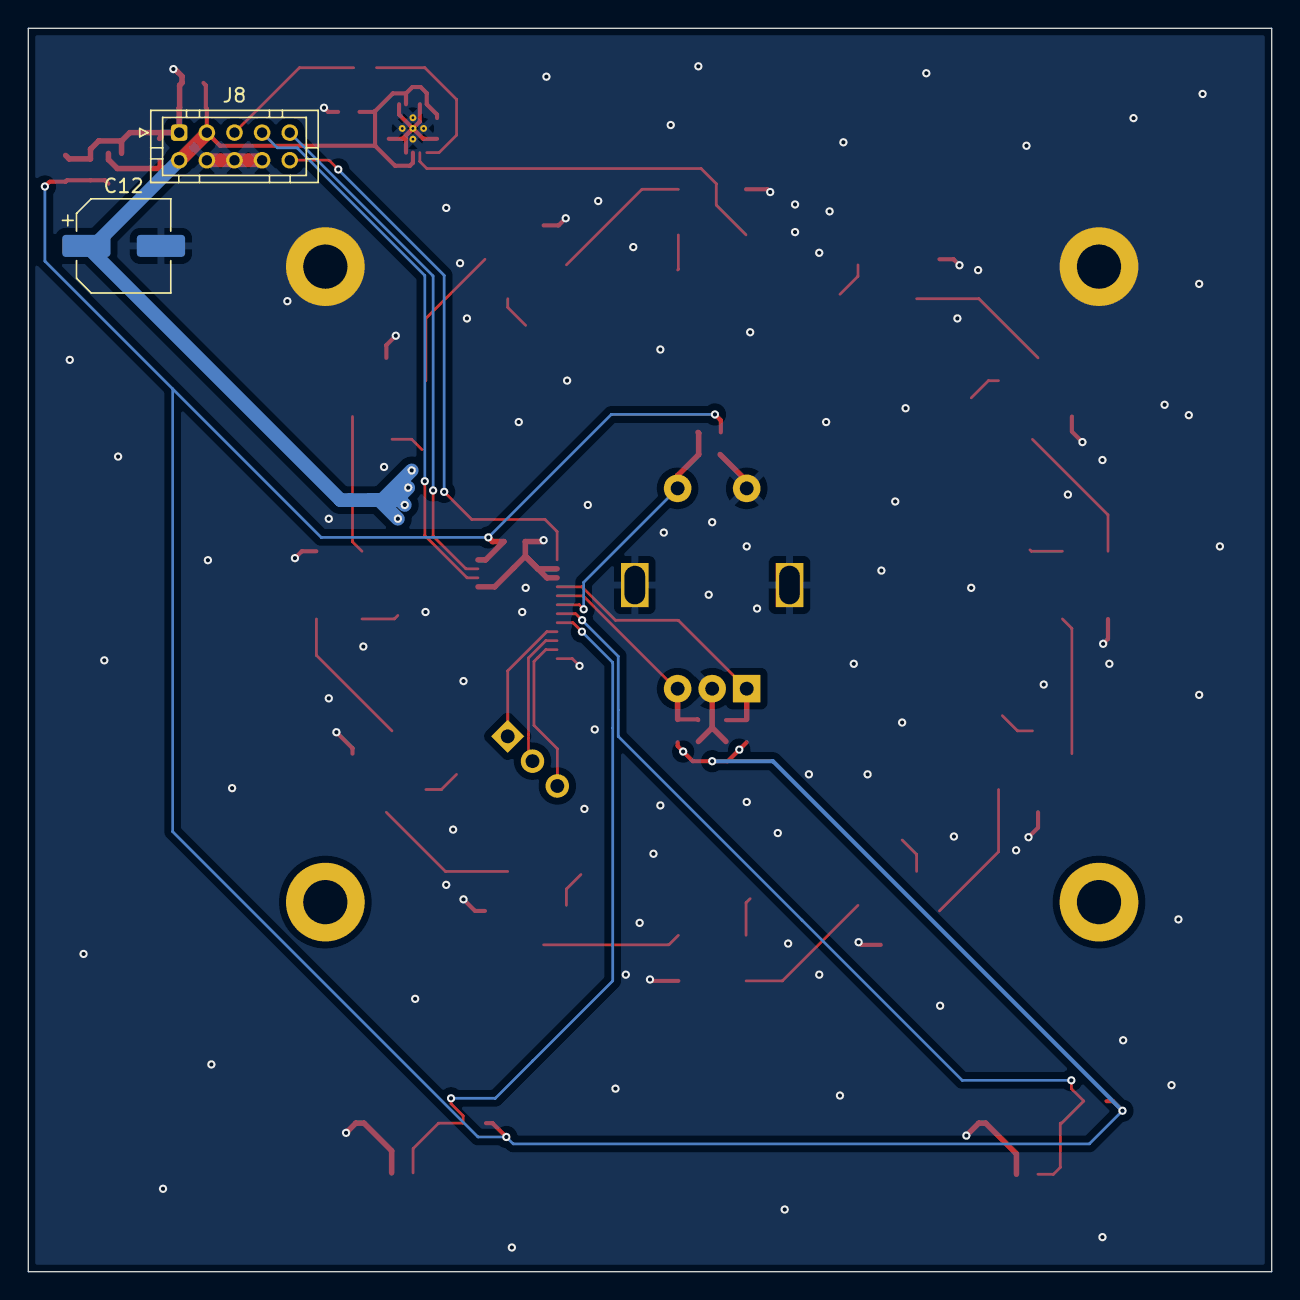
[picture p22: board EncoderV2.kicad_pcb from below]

Board: 2 copper layers, 90.0 x 90.0 mm, 43 parts (2 on the bottom side), 28 nets.

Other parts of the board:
MP1, MP2, MP3, MP4: MountingHole_3.2mm_M3_ISO7380_Pad

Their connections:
GND: MP1.1, MP2.1; also elsewhere on the board

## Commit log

2025-08-20 added KiCad files
    [Tisch.kicad_pcb, Tisch.kicad_sch]
2025-08-20 added Raspi, ESP32 etc
    [Tisch.kicad_sch, esp32.kicad_sch, fan.kicad_sch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]
2025-08-25 Initial commit of project source code
    [QCC5125.kicad_sch, QTT5125.kicad_sch, Tisch.kicad_sch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]
2025-08-25 feat: Improve .gitignore and remove tracked binaries/backups
    [Tisch.kicad_sch, spdif.kicad_sch, untitled.kicad_sch]
2025-08-25 fix: Correct .gitignore for #auto_saved_files and update project
    [Tisch.kicad_sch, adc.kicad_sch, untitled.kicad_sch]
2025-08-26 updated schematics
    [ADAU1451.kicad_sch, QCC5125.kicad_sch, Tisch.kicad_sch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]
2025-08-26 updated schematics and added MSP4030 Docs
    [4.0inch_48P_0.8mm.PcbLib, Configuring options.txt, EC11E15244B2.stp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]
2025-08-27 updated button name and gitignore to (for now) block lvgl stuff
    [encoder.kicad_sch]
2025-09-25 Saving my work on PCB and other files
    [B10B-PHDSS_LF__SN__P_.stp, EC11E15244B2.stp, Encoder.kicad_sch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]
2025-09-26 Refactor PlaybackManager to ensure track item is checked before accessing its properties
    - Added check for `results.get('item')` in `PlaybackManager.current_playback()`.
    - Updated image loading with a user-agent header for compatibility.
    - Added type ignore comment for mqtt.Client initialization.
    UI/Docker/main.py
2025-11-26 Update PCB/Schematic files, scripts and just refractured
    [EncoderV1.kicad_pcb, EncoderV2.kicad_pcb, Stereo_smart.kicad_sch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]
2026-01-07 Stop tracking large binary files
    [4.0inch_48P_0.8mm.PcbLib, Configuring options.txt, FT6336U_Register.xlsx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]
